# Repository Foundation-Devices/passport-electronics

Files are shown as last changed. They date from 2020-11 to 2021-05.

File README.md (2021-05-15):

# Passport Electronics

This repository contains the production circuit designs for Passport, an open source Bitcoin hardware wallet made by Foundation Devices.

main board block diagram

Above is a basic block diagram for Passport's Main Board.

## Project Structure
Passport consists of three circuit boards:
- Main Board
- Camera Board
- Battery Board

**Main Board** contains most of the components, including the processor and secure element.

**Camera Board** contains the camera and attaches to the Main Board.

**Battery Board** contains two variants – North and South – that are populated with different components. Notably, the Battery Board South contains pogo pins that provide power to the Main Board.

### Folder Organization
Each folder contains three subfolders:
- Assembly
- Fabrication
- Source Files

**Assembly** contains data for assembling components onto a bare circuit board. It includes drawings, bill of materials, and coordinates for pick-and-place and test points.

**Fabrication** contains data for the circuit board fabricator. It includes drawings, Gerber files, and coordinates for drilling and test points.

**Source Files** contains circuit board designs. It includes circuit schematics and Altium design files.

Circuit designs can only be opened with Altium. We are exploring exporting these designs in multiple file formats, including formats that can be used with open source PCB design software.

If you are interested in using KiCAD, you may try this Altium to KiCAD converter: https://github.com/thesourcerer8/altium2kicad/.

### Documenting Changes
This repository includes a CHANGES.txt file. We will document all design changes in this file. If you submit a pull request that makes changes to the circuit designs, please update CHANGES.txt with a brief description of your changes.

## Open Source Components
Passport's Main Board incorporates an open-source schematic from the [Betrusted project](https://github.com/betrusted-io/betrusted-hardware-xt). Specifically, we implemented Betrusted's [Avalance Noise Source](https://betrusted.io/avalanche-noise) design into Passport to serve as a true random number generator that does not rely on black-box silicon. Thank you to the Betrusted team for open sourcing their excellent work.

## Security Vulnerability Disclosure
Please report suspected security vulnerabilities in private to security@foundationdevices.com. Please do NOT create publicly viewable issues for suspected security vulnerabilities.

## Licensing
This project, and every file included in this repository, is licensed under CERN-OHL-S v2 – a viral, copyleft, open source license. CERN-OHL-S v2 is similar in goals to GPLv3, but is specifically designed for hardware projects.

You are welcome to use these designs for any purpose, but you must comply with the terms of the license. This includes licensing derivative work as CERN-OHL-S v2, preserving copyright notices, and more. Instructions are included in LICENSE_GUIDE.txt. Feel free to contact us with any questions about licensing.

Included in this repository in LICENSE.txt is the full text of CERN-OHL-S v2.

### License Notice
You may redistribute and modify this source and make products using it
under the terms of the CERN-OHL-S v2 (https://ohwr.org/cern_ohl_s_v2.txt).

This source is distributed WITHOUT ANY EXPRESS OR IMPLIED WARRANTY,
INCLUDING OF MERCHANTABILITY, SATISFACTORY QUALITY AND FITNESS FOR A
PARTICULAR PURPOSE. Please see the CERN-OHL-S v2 for applicable conditions.

Source location: foundationdevices.com/passport-electronics

As per CERN-OHL-S v2 section 4, should You produce hardware based on this
source, You must where practicable and applicable maintain the Source Location
visible (1) on the packaging of the hardware, (2) on the circuit board(s) via
silkscreen or copper, (3) in any documentation, and (4) on other products you
make using this source.

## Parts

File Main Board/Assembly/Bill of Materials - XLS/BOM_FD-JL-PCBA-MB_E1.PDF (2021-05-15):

Line # | Fitted | Rev | Name | Description | Designator | Quantity | Manufacturer 1 | Manufacturer Part Number 1 | Manufacturer 2 | Manufacturer Part Number 2
| Not Fitted | | 6-SNL-170(N) | Tactile Components. 6mm star dome tactile switch. | SW1, SW2, SW3, SW4, SW5, SW6, SW7, SW8, SW9, SW10, SW11, SW12, SW13, SW14, SW15, SW16, SW17, SW18 | 0
1 | Fitted | E1 | FD-JL-PCB-MB | PCB - Juliet - Main Board | PCB1 | 1
2 | Fitted | | 1-2328702-0 | 10 Position FPC Connector Contacts, Top and Bottom 0.020" (0.50mm) Surface Mount, Right Angle | J2 | 1 TE Connectivity | AMP | 1-2328702-0
4 | Fitted | | 74AUP1G09GW,125 | IC GATE AND 1CH 2-INP 5TSSOP | U1 | 1 Nexperia | | 74AUP1G09GW,125
5 | Not Fitted | | 74LVC1G04GW,125 | Inverter IC 1 Channel 5-TSSOP | U19 | 0 Nexperia | | 74LVC1G04GW,125
6 | Fitted | | 0475710001 | CONN MICRO SD CARD PUSH-PULL R/A | J1 | 1 Molex | | 0475710001
7 | Fitted | | ADP5587ACPZ-R7 | I/O Expander 18 I²C 400kHz 24-LFCSP-WQ (4x4) | U4 | 1 Analog Devices | | ADP5587ACPZ-R7
8 | Fitted | | ATECC608A-MAHCZ-T | Cryptographic Co-Processor with Secure Hardware-Based Key Storage 1-Wire Interface 8-Pin UDFN T/R | U10 | 1 Microchip | | ATECC608A-MAHCZ-T
9 | Not Fitted | | B3U-1000P | Tactile Switch SPST-NO Top Actuated Surface Mount | SW19, SW20 | 0 Omron | | B3U-1000P
10 | Fitted | | BZT585B15T-7 | Zener Diode 15V 350mW ±2% Surface Mount SOD-523 | D2, D3 | 2 Diodes | | BZT585B15T-7
11 | Fitted | | CAP CER 0.047uF 10V 10% X7R 0402 | 0.047µF ±10% 10V Ceramic Capacitor X7R 0402 (1005 Metric) | C53 | 1 Murata | | GRM155R71A473KA01D
12 | Fitted | | CAP CER 0.1uF 16V 10% X7R 0402 | 0.1µF ±10% 16V Ceramic Capacitor X7R 0402 (1005 Metric) | C1, C3, C5, C6, C7, C8, C9, C10, C11, C12, C14, C15, C18, C20, C22, C23, C25, C26, C29, C33, C34, C43, C44, C48, C52 | 25 Murata | | GCM155R71C104KA55D
12 | Not Fitted | | CAP CER 0.1uF 16V 10% X7R 0402 | 0.1µF ±10% 16V Ceramic Capacitor X7R 0402 (1005 Metric) | C2, C19 | 0 Murata | | GCM155R71C104KA55D
13 | Fitted | | CAP CER 1uF 25V 10% X5R 0402 | ±10% 25V Ceramic Capacitor X5R 0402 (1005 Metric) | C45 | 1 Samsung | | CL05A105KA5NQNC
14 | Not Fitted | | CAP CER 1.5pF 50V C0G 0402 | 1.5pF ±0.25pF 50V Ceramic Capacitor C0G, NP0 0402 (1005 Metric) | C54 | 0 Samsung | | CL05C1R5CB5NNNC
15 | Fitted | | CAP CER 4.7uF 16V 10% X5R 0603 | 4.7µF ±10% 16V Ceramic Capacitor X5R 0603 (1608 Metric) | C16, C37 | 2 TDK | | C1608X5R1C475K080AC
16 | Fitted | | CAP CER 10uF 6.3V 20% X5R 0603 | 10µF ±20% 6.3V Ceramic Capacitor X5R 0603 (1608 Metric) | C30, C31, C32, C36, C39 | 5 Samsung | | CL10A106MQ8NNNC
17 | Fitted | | CAP CER 22uF 16V 10% X5R 0805 | 22µF ±10% 16V Ceramic Capacitor X5R 0805 (2012 Metric) | C24, C27, C28 | 3 Samsung | | CL21A226KOQNNNE
18 | Fitted | | CAP CER 220pF 50V 5% C0G 0402 | 220pF ±5% 50V Ceramic Capacitor C0G, NP0 0402 (1005 Metric)C42, C47 | | 2 Samsung | | CL05C221JB5NNNC
19 | Fitted | | CAP CER 560pF 50V 10% X7R 0402 | 560pF ±10% 50V Ceramic Capacitor X7R 0402 (1005 Metric) | C21 | 1 Samsung | | CL05B561KB5NNNC
20 | Fitted | | CAP CER 1000pF 1000V 10% X7R 0805 | 1000pF ±10% 1000V (1kV) Ceramic Capacitor X7R 0805 (2012 Metric) | C17 | 1 KEMET | | C0805C102KDRACTU
21 | Fitted | | CAP CER 1500pF 50V 10% X7R 0402 | 1500pF ±10% 50V Ceramic Capacitor X7R 0402 (1005 Metric) | C41, C46, C51 | 3 Murata | | GCM155R71H152KA37D
21 | Not Fitted | | CAP CER 1500pF 50V 10% X7R 0402 | 1500pF ±10% 50V Ceramic Capacitor X7R 0402 (1005 Metric) | C38, C49 | 0 Murata | | GCM155R71H152KA37D
22 | Fitted | | CAP CER 2.2uF 6.3V 10% X5R 0402 | 2.2µF ±10% 6.3V Ceramic Capacitor X5R 0402 (1005 Metric) | C4, C13, C40, C50, C58 | 5 Samsung | | CL05A225KQ5NSNC
23 | Fitted | | CAP CER 10uF 16V 20% X5R 0603 | 10µF ±20% 16V Ceramic Capacitor X5R 0603 (1608 Metric) | C35 | 1 Murata | | GRM188R61C106MA73D
24 | Fitted | | CB2518T1R5M | 1.5µH Unshielded Wirewound Inductor 1.4A 91mOhm Max 1007 (2518 Metric) | L1 | 1 Taiyo Yuden | | CB2518T1R5M
25 | Fitted | | CB2518T4R7MRV | 4.7µH Unshielded Wirewound Inductor 820mA 130mOhm Max 1007 (2518 Metric) | L2, L3 | 2 Taiyo Yuden | | CB2518T4R7MRV
26 | Fitted | | CSTNE8M00G550000R0 | 8MHz Ceramic Resonator Built in Capacitor 33pF ±0.2% 40 Ohms -40°C ~ 85°C Surface Mount | X2 | 1 Murata | | CSTNE8M00G550000R0
27 | Fitted | | DMG2305UX-7 | P-Channel 20V 4.2A (Ta) 1.4W (Ta) Surface Mount SOT-23 | Q1 | 1 Diodes | | DMG2305UX-7
28 | Fitted | | KB DELPS2.DI-THVG-2J8L-Z555 | Blue 466nm LED Indication - Discrete 2.8V 2-SMD 0603 | LED2 | 1 Osram Opto | | KB DELPS2.DI-THVG-2J8L-Z555
29 | Fitted | | LA0151CS-TLM-E | Optical Sensor Ambient 550nm Current 4-WFBGA, CSPBGA | U5 | 1 ON | Semiconductor | LA0151CS-TLM-E
30 | Fitted | | LMV981MG/NOPB | General Purpose Amplifier 1 Circuit Rail-to-Rail SC-70-6 | U14, U16, U18 | 3 TI National | Semiconductor | LMV981MG/NOPB
31 | Fitted | | LSS-110-02-L-DV-A-K-TR | 20 Position Connector Self Mating, Non-Gendered Surface Mount Gold | P1 | 1 Samtec | | LSS-110-02-L-DV-A-K-TR
32 | Not Fitted | | LTST-C191KGKT | Green 571nm LED Indication - Discrete 2V 0603 (1608 Metric) | LED4 | 0 Vishay Lite-On | | LTST-C191KGKT
33 | Fitted | | LTST-C191KRKT | Red 631nm LED Indication - Discrete 2V 0603 (1608 Metric) | LED1 | 1 Vishay Lite-On | | LTST-C191KRKT
33 | Not Fitted | | LTST-C191KRKT | Red 631nm LED Indication - Discrete 2V 0603 (1608 Metric) | LED3 | 0 Vishay Lite-On | | LTST-C191KRKT
34 | Fitted | | MCP1501T-25E/RW | Series Voltage Reference IC 2.5V ±0.1% 8-WDFN (2x2) | U20 | 1 Microchip | | MCP1501T-25E/RW
35 | Fitted | | MCP1643-I/MC | LED Driver IC 1Output DC DC Regulator Step-Up (Boost) PWM Dimming 550mA 8-DFN (2x3) | U15 | 1 Microchip | | MCP1643-I/MC
36 | Fitted | | MLZ1608M220WT000 | 22µH Shielded Multilayer Inductor 150mA 2.4Ohm 0603 (1608 Metric) | L4 | 1 TDK | | MLZ1608M220WT000
37 | Fitted | | MMBT3906-7-F | TRANS PNP 40V 0.2A SOT23-3 | Q2 | 1 Diodes Zetex | | MMBT3906-7-F
38 | Fitted | | MX25V1635FZUI | FLASH - NOR Memory IC 16Mb (2M x 8) SPI - Quad I/O 80MHz 8-USON (2x3) | U9 | 1 Macronix | | MX25V1635FZUI
39 | Fitted | | NTK3043NT1G | N-Channel 20V 210mA (Ta) 310mW (Ta) Surface Mount SOT-723 | U8 | 1 ON | Semiconductor | NTK3043NT1G
40 | Fitted | | PUSB3AB4Z | TVS DIODE 3.3V 5V DFN2510A-10 | U6, U7 | 2 Nexperia | | PUSB3AB4Z
41 | Fitted | | RB751S40T1G | Diode Schottky 30V 30mA (DC) Surface Mount SOD-523 | D1 | 1 ON | Semiconductor | RB751S40T1G
42 | Fitted | | RES4T 0.05OHM 0.5% 1/2W 1206 | 50mOhms ±0.5% 0.5W, 1/2W Chip Resistor 1206 (3216 Metric) Current Sense | R28 | 1 Ohmite | | LVK12R050DER | Vishay Dale | WSK1206R0500FEA18
43 | Fitted | | RES 0OHM JUMPER 1/16W 0402 | 0Ohms Jumper 0.063W, 1/16W Chip Resistor 0402 (1005 Metric) | R7, R9, R54, R57 | 4 Vishay | | CRCW04020000Z0ED
43 | Not Fitted | | RES 0OHM JUMPER 1/16W 0402 | 0Ohms Jumper 0.063W, 1/16W Chip Resistor 0402 (1005 Metric) | R53, R62, R63, R67, R73 | 0 Vishay | | CRCW04020000Z0ED
44 | Fitted | | RES 1.0K 1/16W 1% 0402 | 1 kOhms ±0.5% 0.063W, 1/16W Chip Resistor 0402 (1005 Metric) Automotive AEC-Q200 Thin Film | R36, R38 | 2 Panasonic | | ERA-2AEB102X
45 | Fitted | | RES 1.0M 1/4W 5% 1206 | 1 MOhms ±5% 0.25W, 1/4W Chip Resistor 1206 (3216 Metric) Moisture Resistant Thick Film | R24 | 1 Yageo | | RC1206JR-071ML
46 | Not Fitted | | RES 1M 1/16W 1% 0402 | 1 MOhms ±1% 0.063W, 1/16W Chip Resistor 0402 (1005 Metric)R8 | | 0 Vishay | | CRCW04021M00FKED
47 | Fitted | | RES 1.8M 1/16W 1% 0402 | 1.8 MOhms ±1% 0.063W, 1/16W Chip Resistor 0402 (1005 Metric) | R35 | 1 Vishay | | CRCW04021M80FKED
48 | Fitted | | RES 4.7K 1/16W 1% 0402 | 4.7 kOhms ±1% 0.063W, 1/16W Chip Resistor 0402 (1005 Metric) Automotive AEC-Q200 Thick Film | R10, R11, R12, R13, R14, R15, R26, R59, R60 | 9 Vishay | | CRCW04024K70FKED
49 | Fitted | | RES 5.1M 1/16W 1% 0402 | 5.1 MOhms ±1% 0.1W, 1/10W Chip Resistor 0402 (1005 Metric)R43, R48 | | 2 Vishay | | CRCW04025M10FKED
50 | Fitted | | RES 6.04OHM 1/16W 1% 0402 | 6.04Ohms ±1% 0.063W, 1/16W Chip Resistor 0402 (1005 Metric) | R41 | 1 Vishay Dale | | CRCW04026R04FKED
51 | Fitted | | RES 10OHM 1/16W 1% 0402 | 10Ohms ±1% 0.063W, 1/16W Chip Resistor 0402 (1005 Metric)R5, R74 | | 2 Vishay | | CRCW040210R0FKED
52 | Fitted | | RES 10K 1/16W 1% 0402 | 10 kOhms ±1% 0.063W, 1/16W Chip Resistor 0402 (1005 Metric) | R3, R16, R17, R18, R19, R20, R21, R22, R27, R46, R51, R55, R56 | 13 Samsung | | RC1005F103CS
52 | Not Fitted | | RES 10K 1/16W 1% 0402 | 10 kOhms ±1% 0.063W, 1/16W Chip Resistor 0402 (1005 Metric) | R23 | 0 Samsung | | RC1005F103CS
55 | Fitted | | RES 21.5K 1/16W 1% 0402 | 21.5 kOhms ±1% 0.063W, 1/16W Chip Resistor 0402 (1005 Metric) | R32 | 1 Vishay | | CRCW040221K5FKED
56 | Fitted | | RES 22K 1/16W 1% 0402 | 22 kOhms ±1% 0.063W, 1/16W Chip Resistor 0402 (1005 Metric) | R6, R25, R33, R52 | 4 Vishay | | CRCW040222K0FKED
58 | Fitted | | RES 47.5K 1/16W 1% 0402 | 47.5 kOhms ±1% 0.063W, 1/16W Chip Resistor 0402 (1005 Metric) | R34 | 1 Vishay | | CRCW040247K5FKED
59 | Fitted | | RES 100K 1/16W 0.5% 0402 | 100 kOhms ±0.5% 0.063W, 1/16W Chip Resistor 0402 (1005 Metric) | R39 | 1 Vishay Dale | | CRCW0402100KDHEDP
60 | Fitted | | RES 100K 1/16W 1% 0402 | 100 kOhms ±1% 0.063W, 1/16W Chip Resistor 0402 (1005 Metric) Automotive AEC-Q200 Thick Film | R1, R2, R4, R30, R40, R42, R47 | 7 Vishay | | CRCW0402100KFKED
60 | Not Fitted | | RES 100K 1/16W 1% 0402 | 100 kOhms ±1% 0.063W, 1/16W Chip Resistor 0402 (1005 Metric) Automotive AEC-Q200 Thick Film | R58, R68 | 0 Vishay | | CRCW0402100KFKED
61 | Fitted | | RES 200K 1/16W 1% 0402 | 200 kOhms ±1% 0.063W, 1/16W Chip Resistor 0402 (1005 Metric) Moisture Resistant Thick Film | R29, R31, R37 | 3 Vishay Dale | | CRCW0402200KFKTD
62 | Fitted | | RES 220K 1/16W 1% 0402 | 220 kOhms ±1% 0.063W, 1/16W Chip Resistor 0402 (1005 Metric) | R45, R50, R61 | 3 Vishay | | CRCW0402220KFKED
63 | Not Fitted | | RES 330OHM 1/16W 1% 0402 | 330Ohms ±1% 0.063W, 1/16W Chip Resistor 0402 (1005 Metric) Moisture Resistant Thick Film | R65, R66 | 0 Vishay | | CRCW0402330RFKED
64 | Fitted | | RES 470K 1/16W 1% 0402 | 470 kOhms ±1% 0.063W, 1/16W Chip Resistor 0402 (1005 Metric) | R44, R49 | 2 Vishay | | CRCW0402470KFKED
65 | Fitted | | SFV4R-2STE1HLF | 4 Position FFC, FPC Connector Contacts, Top 0.020" (0.50mm) Surface Mount, Right Angle | J3 | 1 Amphenol ICC / | FCI | SFV4R-2STE1HLF
66 | Fitted | | STM32H753VIT6 | ARM® Cortex®-M7 STM32H7 Microcontroller IC 32-Bit 480MHz 2MB (2M x 8) FLASH 100-LQFP (14x14) | U2 | 1 STMicroelectronic | s | STM32H753VIT6
67 | Not Fitted | | TPS3840DL27DBVR | Supervisor 2.7V Open Drain 1 Channel SOT-23-5 | U3 | 0 Texas Instruments TPS3840DL27DBVR
68 | Fitted | | TPS61158DRVR | LED Driver IC 1Output DC DC Regulator Step-Up (Boost) PWM Dimming 30mA 6-WSON (2x2) | U17 | 1 Texas Instruments TPS61158DRVR
69 | Fitted | | TPS61220DCKR | Boost Switching Regulator IC Positive Adjustable 1.8V 1 Output 200mA (Switch) 6-TSSOP, SC-88, SOT-363 | U13 | 1 Texas Instruments TPS61220DCKR
70 | Fitted | | TPS63030DSKR | Buck-Boost Switching Regulator IC Positive Adjustable 1.2V 1 Output 900mA (Switch) 10-WFDFN Exposed Pad | U11 | 1 Texas Instruments TPS63030DSKR
71 | Fitted | | TPS79928YZUR | Linear Voltage Regulator IC 1Output 200mA 5-DSBGA (1x1.37) | U21 | 1 Texas Instruments TPS79928YZUR
72 | Fitted | | XC6192AA05ER-G | Power Switch/Driver 1:1 P-Channel 400mA USP-8B06 | U12 | 1 Torex | | XC6192AA05ER-G

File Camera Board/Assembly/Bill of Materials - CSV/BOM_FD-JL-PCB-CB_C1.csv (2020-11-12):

Line # | Fitted | Rev | Name | Description | Designator | Quantity | Manufacturer 1 | Manufacturer Part Number 1
1 | Fitted |  | CAP CER 4.7uF 16V 10% X5R 0603 | 4.7µF ±10% 16V Ceramic Capacitor X5R 0603 (1608 Metric) | C1, C2, C5, C6 | 4 | TDK | C1608X5R1C475K080AC
2 | Fitted |  | CAP CER 0.1uF 16V 10% X7R 0402 | 0.1µF ±10% 16V Ceramic Capacitor X7R 0402 (1005 Metric) | C3, C4, C7, C8, C9 | 5 | Murata | GCM155R71C104KA55D
3 | Fitted |  | BLM18PG221SH1D | FERRITE BEAD 220 OHM 0603 1LN | L1, L2 | 2 | Murata | BLM18PG221SH1D
4 | Fitted |  | LSS-110-02-L-DV-A-K | 20 Position Connector Self Mating, Non-Gendered Surface Mount Gold | P1 | 1 | Samtec | LSS-110-02-L-DV-A-K
5 | Fitted | C1 | FD-JL-PCB-CB | PCB - Juliet - Camera Board | PCB1 | 1
6 | Fitted |  | RES 4.7K 1/16W 1% 0402 | 4.7 kOhms ±1% 0.063W, 1/16W Chip Resistor 0402 (1005 Metric) Automotive AEC-Q200 Thick Film | R1, R2 | 2 | Vishay | CRCW04024K70FKED
7 | Not Fitted |  | RES 0 OHM JUMPER 1/16W 0402 | 0 Ohms Jumper 0.063W, 1/16W Chip Resistor 0402 (1005 Metric) | R4 | 0 | Vishay | CRCW04020000Z0ED
7 | Fitted |  | RES 0 OHM JUMPER 1/16W 0402 | 0 Ohms Jumper 0.063W, 1/16W Chip Resistor 0402 (1005 Metric) | R5 | 1 | Vishay | CRCW04020000Z0ED
8 | Fitted |  | OVM7690-RYAA | SENSOR CAMERA CMOS 20CAMERACUBE | U1 | 1 | OmniVision Technologies | OVM7690-R20A
9 | Fitted |  | DSC6001HE2A-024.0000 | XO (Standard) CMOS Oscillator 1.8V ~ 3.3V Enable/Disable 4-SMD, No Lead | X1 | 1 | Microchip | DSC6001HE2A-024.0000

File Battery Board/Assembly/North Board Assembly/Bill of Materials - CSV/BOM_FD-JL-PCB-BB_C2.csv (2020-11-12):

Line # | Fitted | Rev | Name | Description | Quantity | Designator | Manufacturer 1 | Manufacturer Part Number 1
1 | Fitted | C2 | FD-JL-PCB-BB | PCB - Juliet - Battery Board | 1 | PCB1
2 | Fitted |  | SMTSO-080-4ET | Surface Mount Nut | 1 | N1 | PennEngineering | SMTSO-080-4ET
3 | Fitted |  | RES 0 OHM JUMPER 1/8W 0805 | 0 Ohms Jumper 0.125W, 1/8W Chip Resistor 0805 (2012 Metric) | 1 | R1 | Vishay | CRCW08050000Z0EA
4 | Fitted |  | 0393-0-00-15-00-00-09-0* | Pin Receptacle Connector 0.065" ~ 0.082" (1.65mm ~ 2.08mm) No Tail Solder | 1 | P2 | Mill-Max | 0393-0-00-15-00-00-09-0*
5 | Fitted |  | 0871-0-57-20-82-14-11-0 | Contact Spring Surface Mount | 1 | P3 | Mill-Max | 0871-0-57-20-82-14-110
6 | Not Fitted |  | 829-22-002-20-002101 | 2 Position Spring Piston Connector Through Hole, Right Angle | 0 | P1 | Mill-Max | 829-22-002-20-002101

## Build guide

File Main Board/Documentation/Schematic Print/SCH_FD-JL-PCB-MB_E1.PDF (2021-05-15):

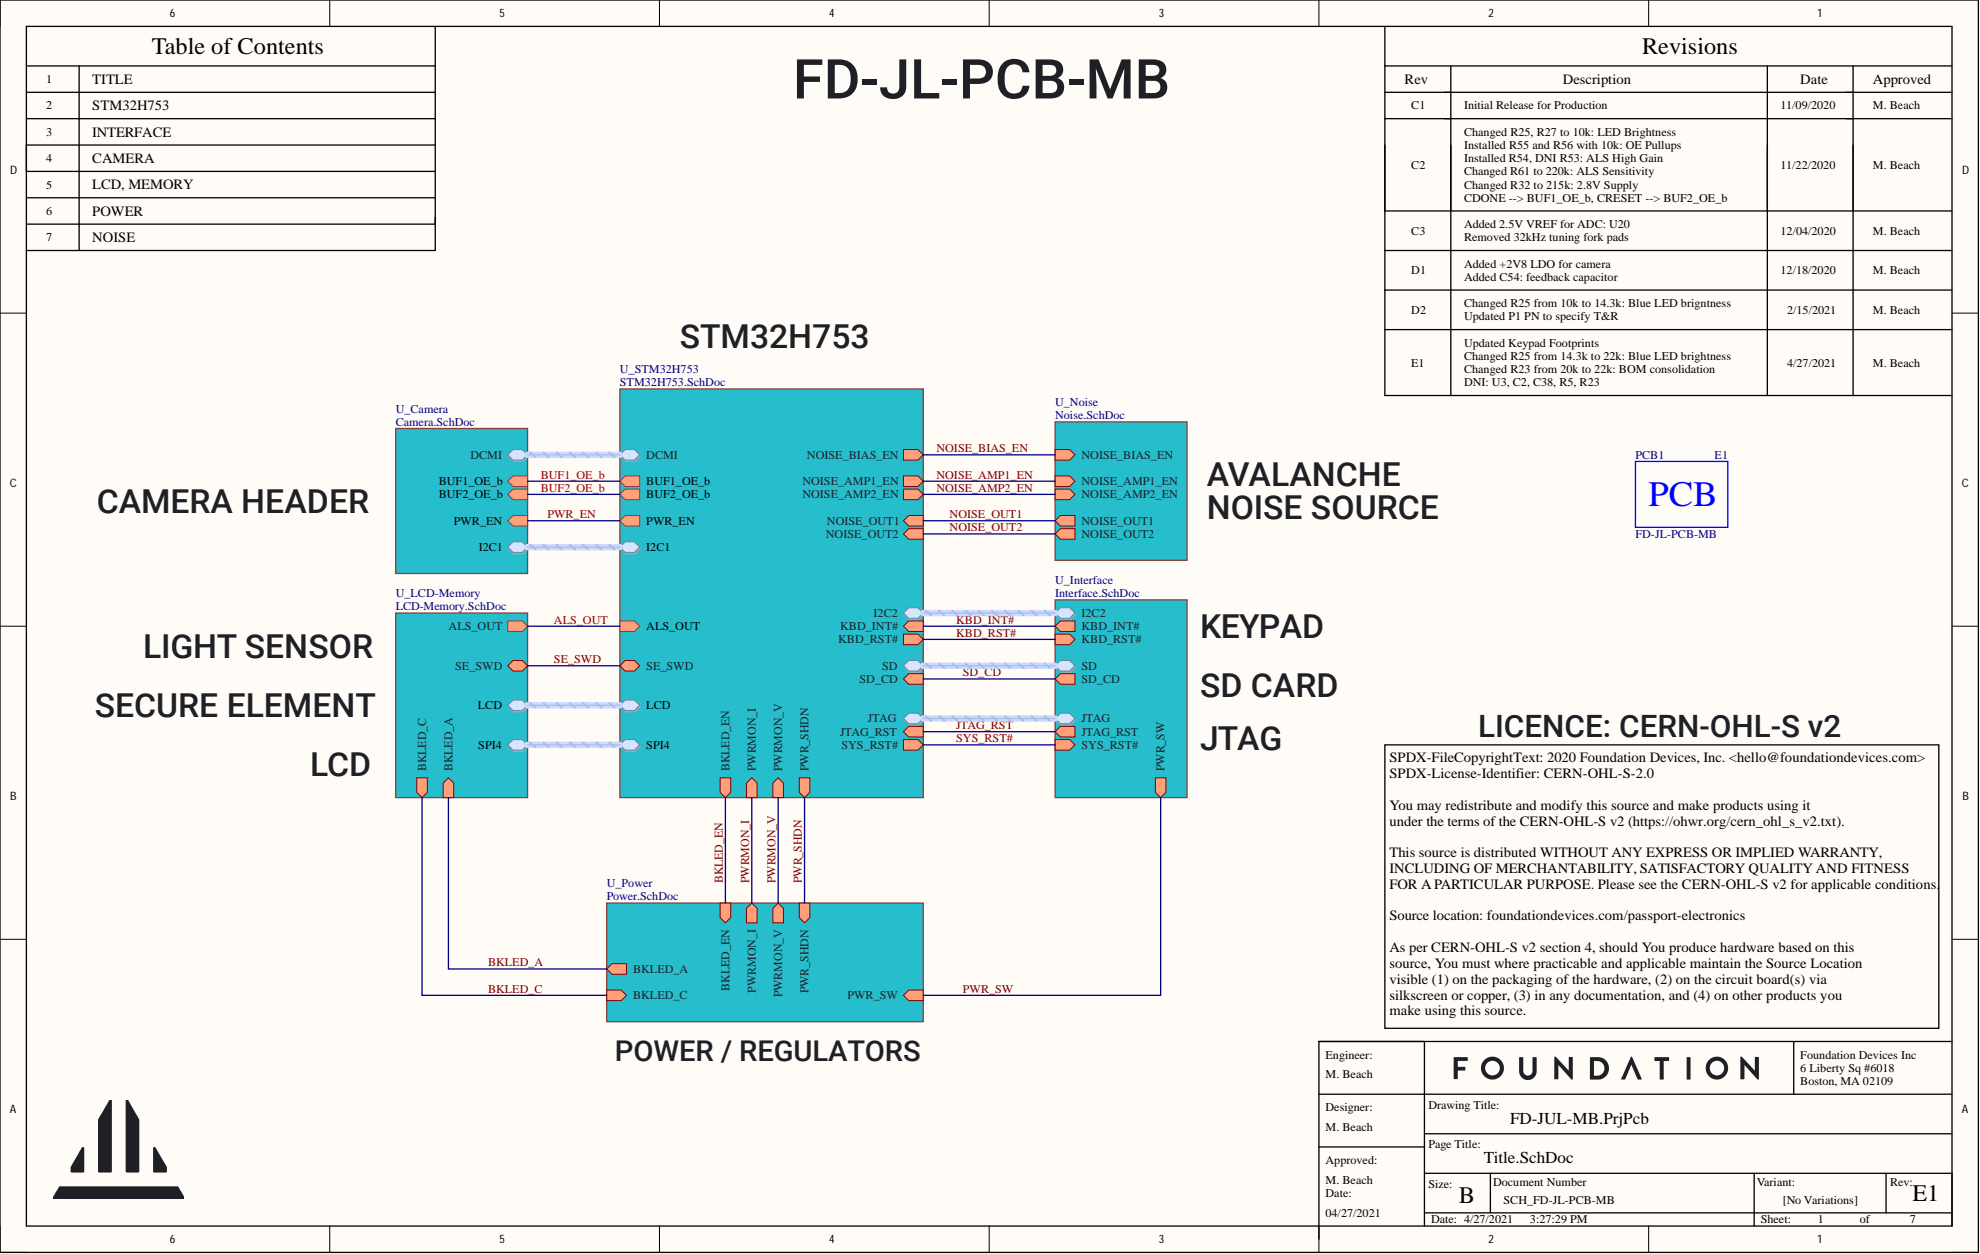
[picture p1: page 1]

FD-JL-PCB-MB

Table of Contents | STM32H753 U_STM32H753 STM32H753.SchDoc | Revisions

TITL E | | Rev | Description | Date | Approve d

234567 | CAMERA

STM32H753 | | C1 | Initial Release for Production | 11/09/2020 | M. Beach

INTERFACE | | C2 | Changed R25, R27 to 10k: LED Brightness Installed R55 and R56 with 10k: OE Pullups Installed R54, DNI R53: ALS High Gain Changed R61 to 220k: ALS Sensitivity Changed R32 to 215k: 2.8V Supply CDONE --> BUF1_OE_b, CRESET --> BUF2_OE_b | 11/22/2020 | M. Beach

LCD, MEMOR Y

POWER

C3 | Added 2.5V VREF for ADC: U20 Removed 32kHz tuning fork pads | 12/04/2020 | M. Beach

NOISE

D1 | Added +2V8 LDO for camera Added C54: feedback capacitor | 12/18/2020 | M. Beach

D2 | Updated P1 PN to specify T&R | 2/15/2021 | M. Beach Changed R25 from 10k to 14.3k: Blue LED brigntness

E1 | Updated Keypad Footprints Changed R25 from 14.3k to 22k: Blue LED brightness Changed R23 from 20k to 22k: BOM consolidation DNI: U3, C2, C38, R5, R23 | 4/27/2021 | M. Beach

BUF1_OE_b | NOISE_AMP1_EN
BUF2_OE_b | NOISE_AMP2_EN

PWR_EN | NOISE_OUT1

SPDX-FileCopyrightText: 2020 Foundation Devices, Inc. <hello@foundationdevices.com>
SPDX-License-Identifier: CERN-OHL-S-2.0 You may redistribute and modify this source and make products using it

under the terms of the CERN-OHL-S v2 (https://ohwr.org/cern_ohl_s_v2.txt).

This source is distributed WITHOUT ANY EXPRESS OR IMPLIED
INCLUDING OF MERCHANTABILITY, SATISFACTORY QUALITY AND FITNESS
FOR

PARTICULAR PURPOSE. Please see the CERN-OHL-S v2 for applicable conditions.

Source location: foundationdevices.com/passport-electronic

As per CERN-OHL-S v2 section 4, should
source,
visible (1) on the packaging of the hardware, (2) on the circuit board(s) via
silkscreen or copper, (3) in any documentation, and (4) on other products you
make using this source.

You produce hardware based on this

You must where practicable and applicable maintain the Source Location

Engineer: | | Foundation Devices Inc 6 Liberty Sq #6018 Boston, MA 02109 M. Beach

Designer: M. Beach | Drawing Title: FD-JUL-MB.PrjPcb

Size: B | Document Number SCH_FD-JL-PCB-MB | Variant: [No Variations] | Rev: E1

Date: 4/27/2021 3:27:29 PM | | Sheet: 1 of

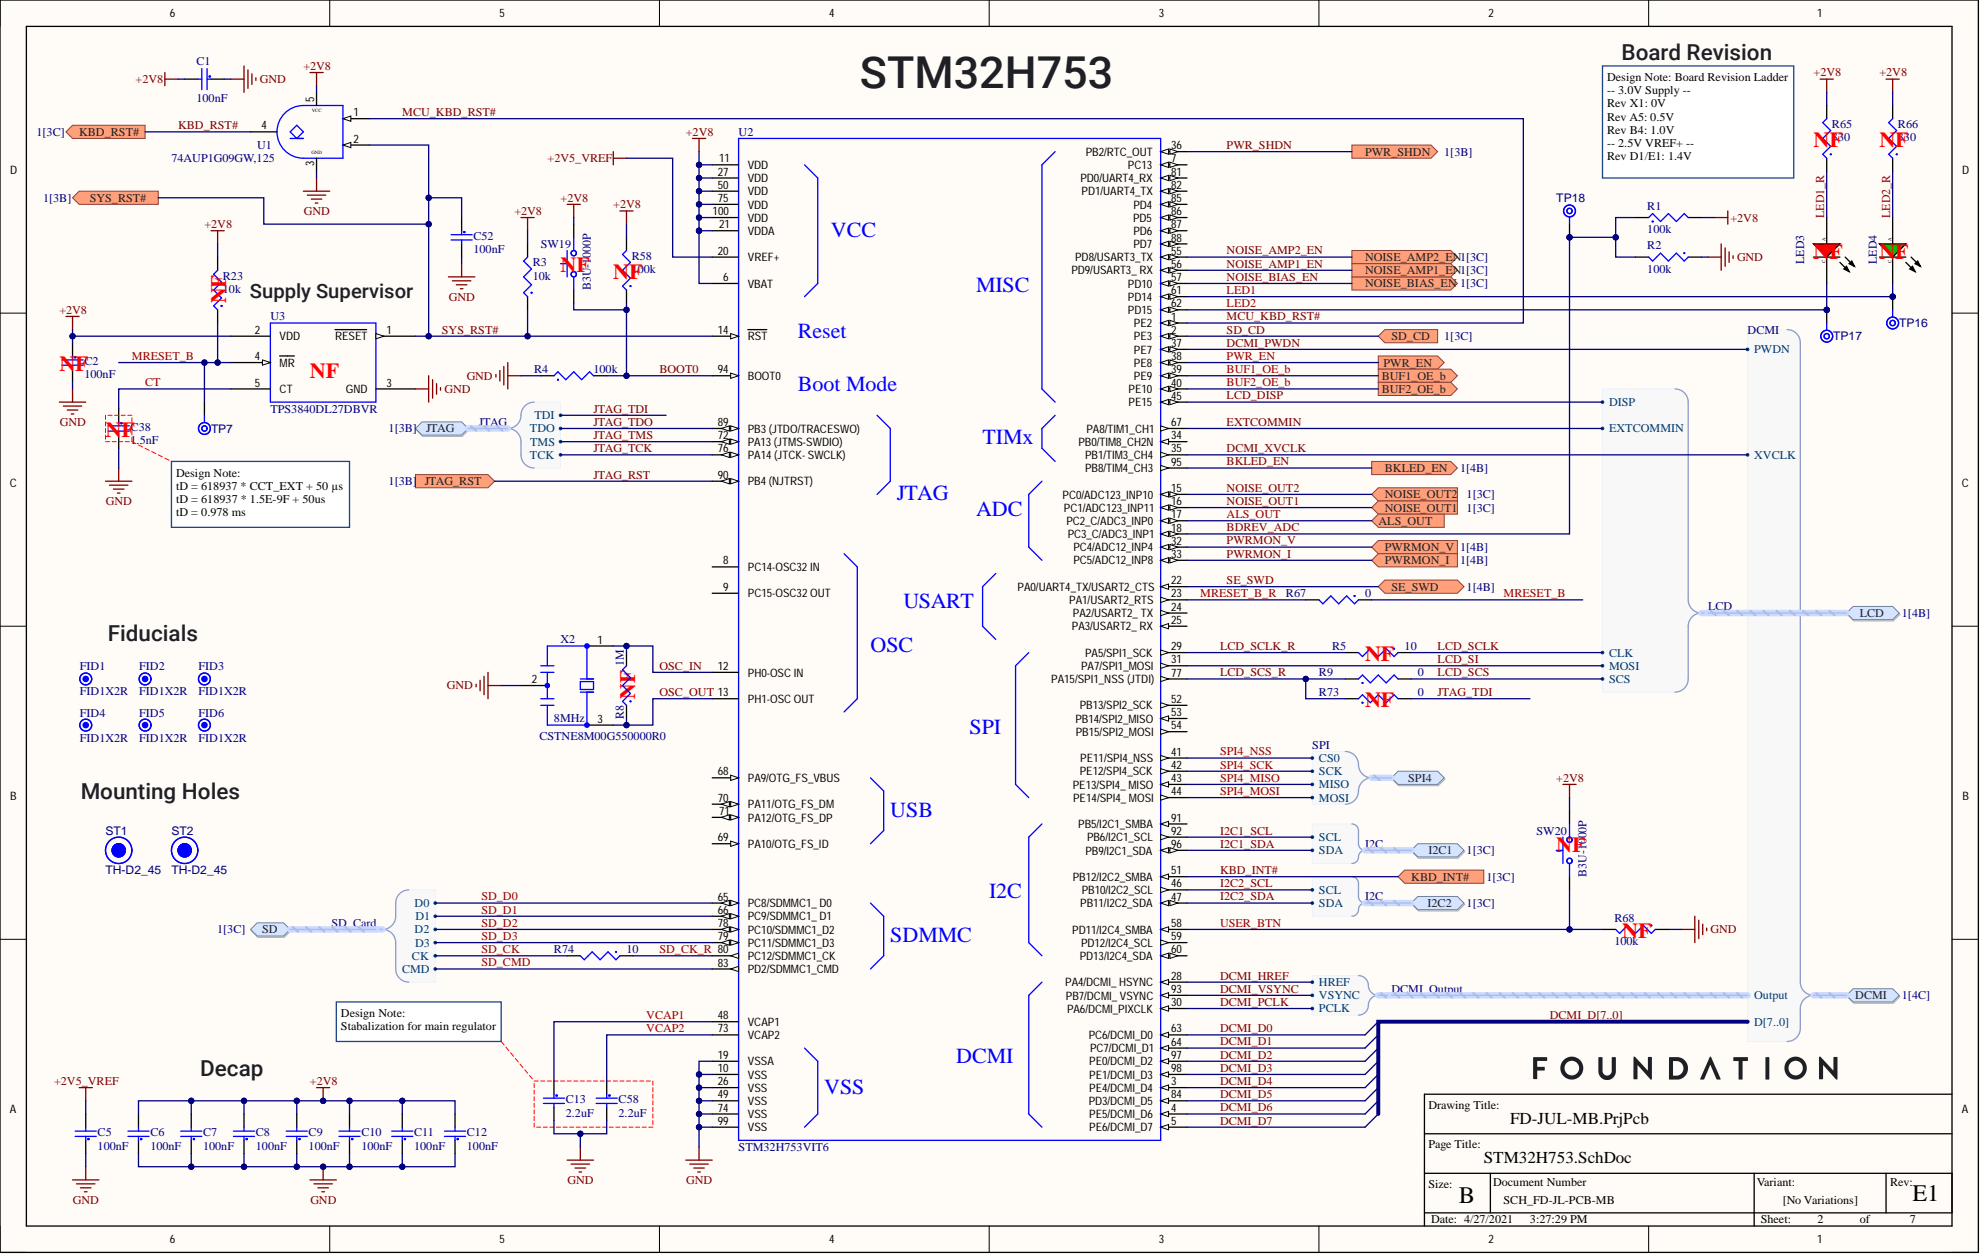
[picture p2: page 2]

VDD 27
VDD 50
VDD 75
VDD 100
VDDA 21

GND

VREF+ 20

NOISE_AMP2_EN NOISE_AMP2_EN1[3C] NOISE_AMP1_EN NOISE_AMP1_EN1[3C] NOISE_BIAS_EN 1[3C] NOISE_BIAS_EN

LED1
LED2

PH1-OSC OUT 13

SPI4_NSS SPI4_SCK SPI4_MISO | R73

Design Note:
Stabalization for main regulator

VCAP2 | VCAP2 73

VSSA 19

FD-JUL-MB.PrjPcb

B | Variant: | Rev:

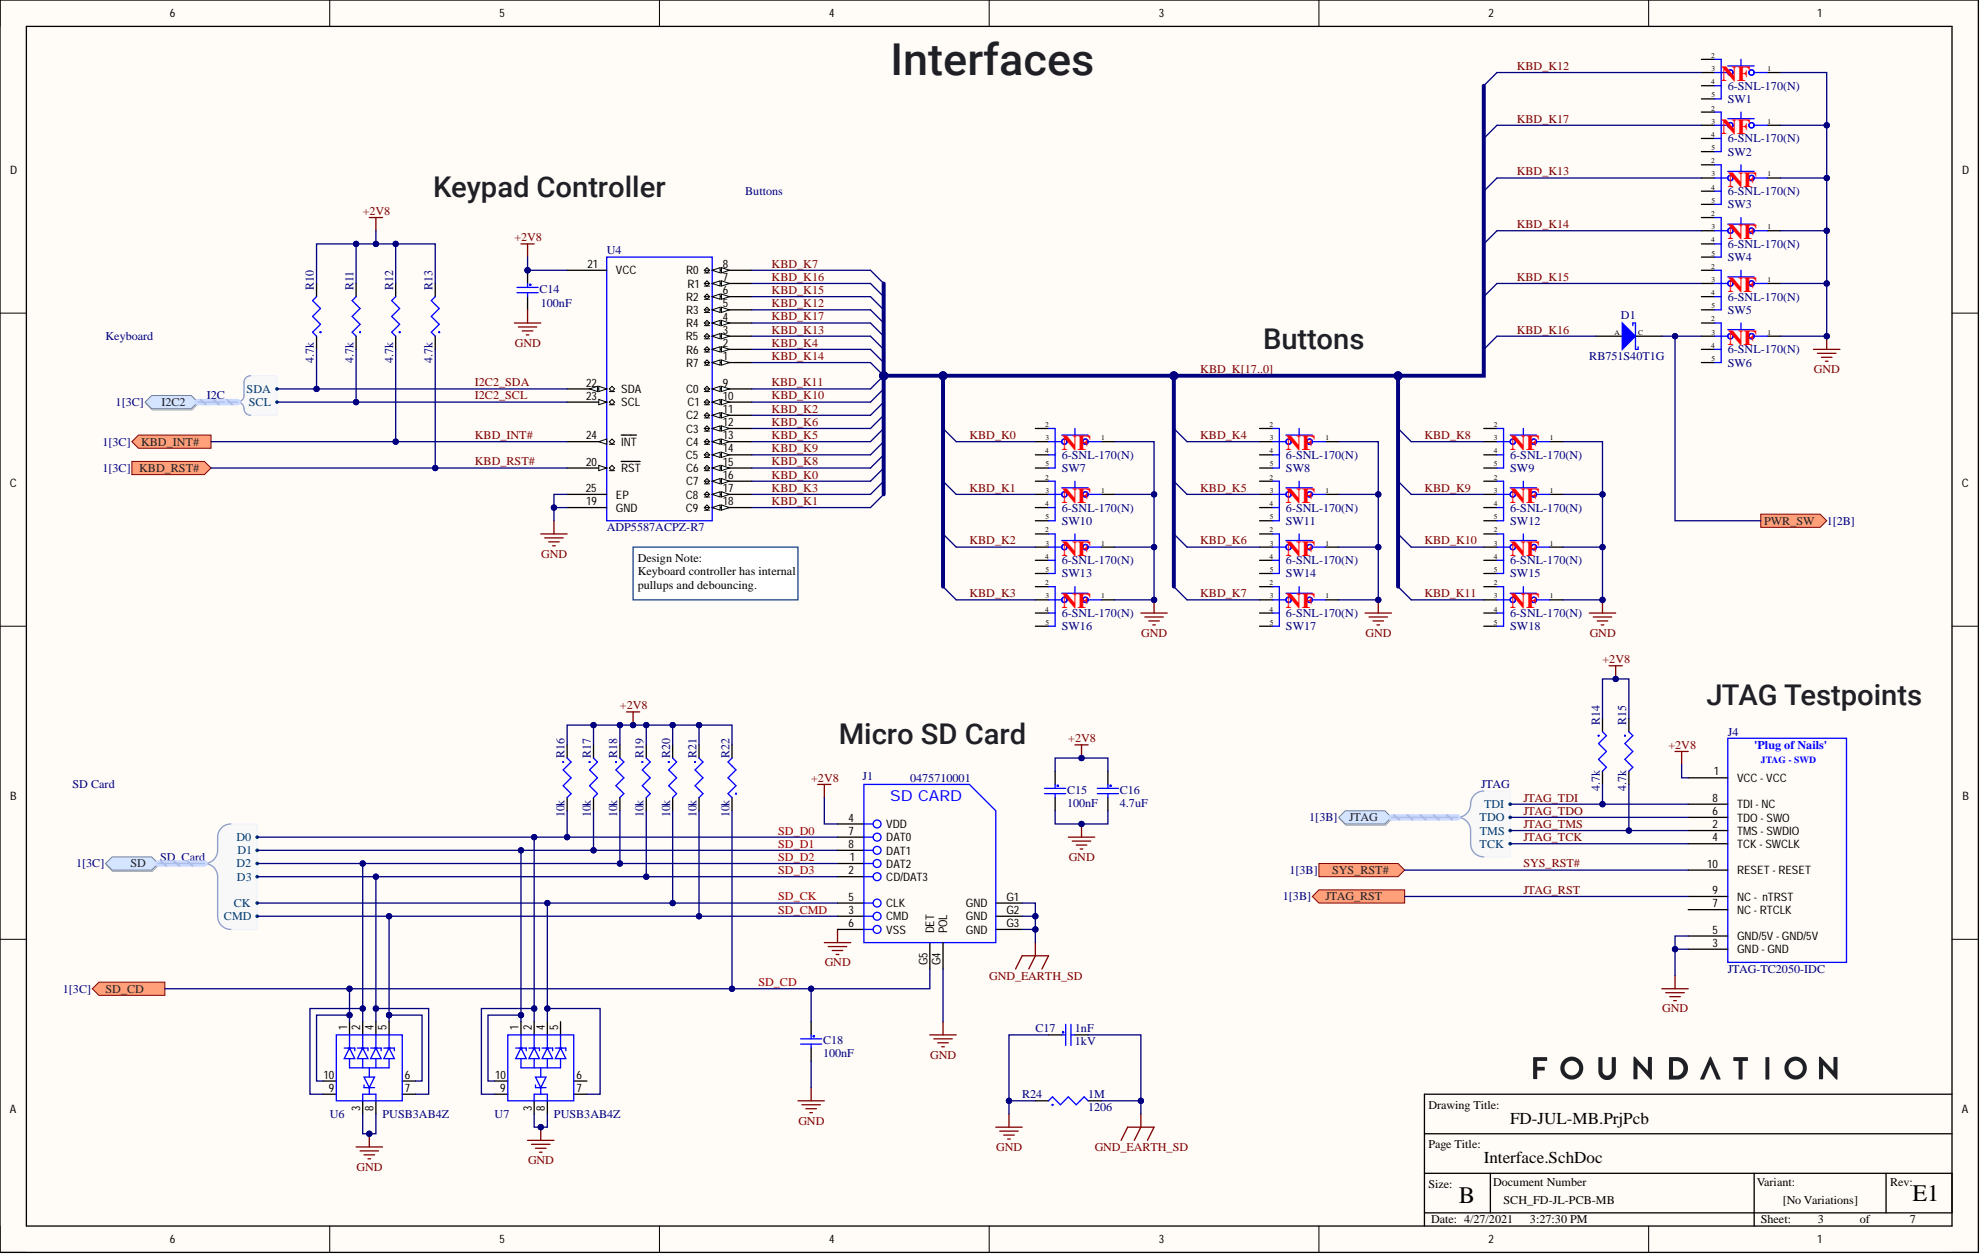
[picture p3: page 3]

Design Note:
Keyboard controller has internal
pullups and debouncing.

FD-JUL-MB.PrjPcb

Size: B | | Rev: E1 Variant:

Date: 4/27/2021 3:27:30 PM | Sheet: 3 of 7

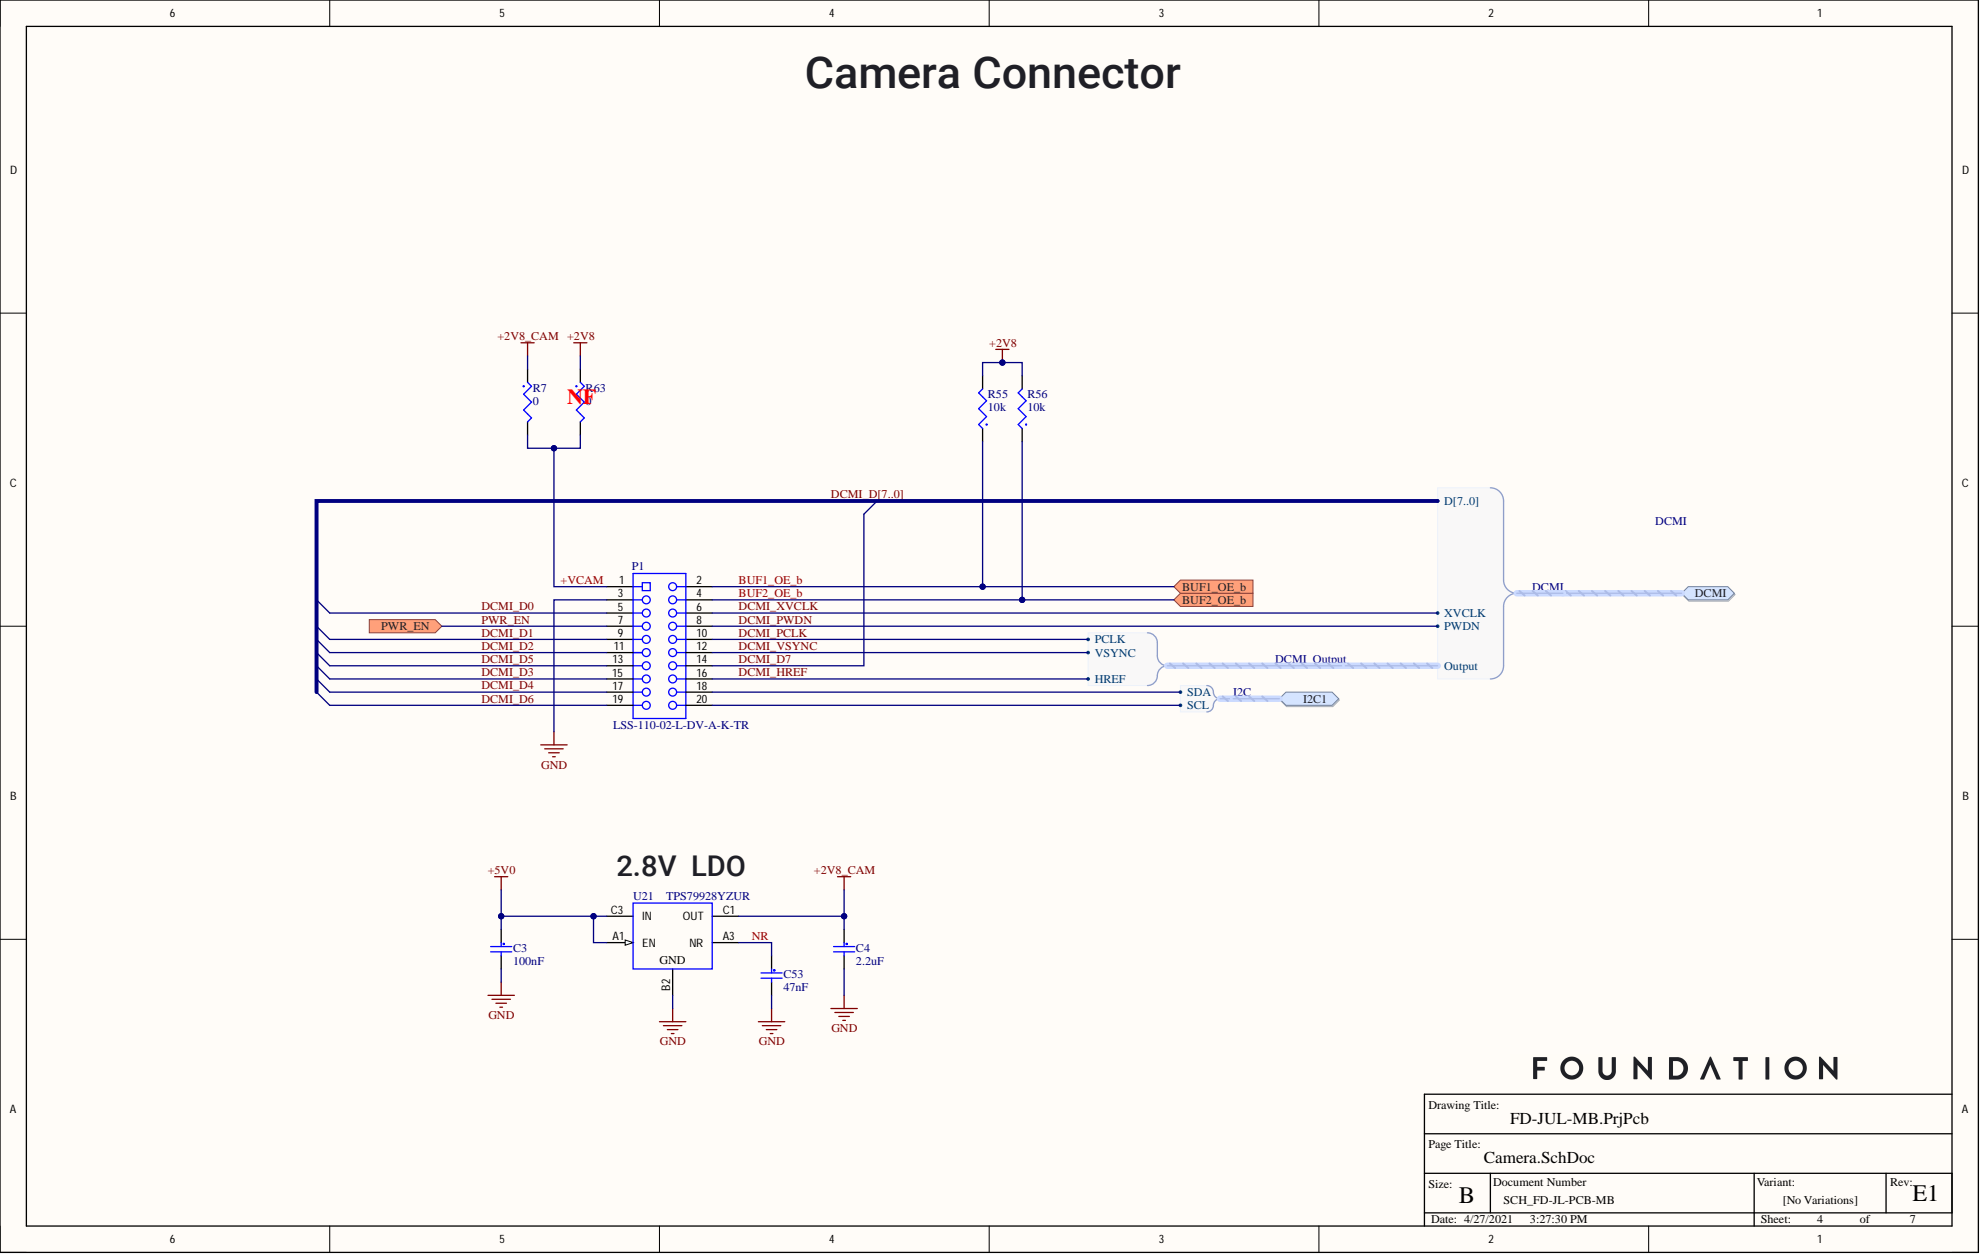
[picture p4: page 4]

FD-JUL-MB.PrjPcb

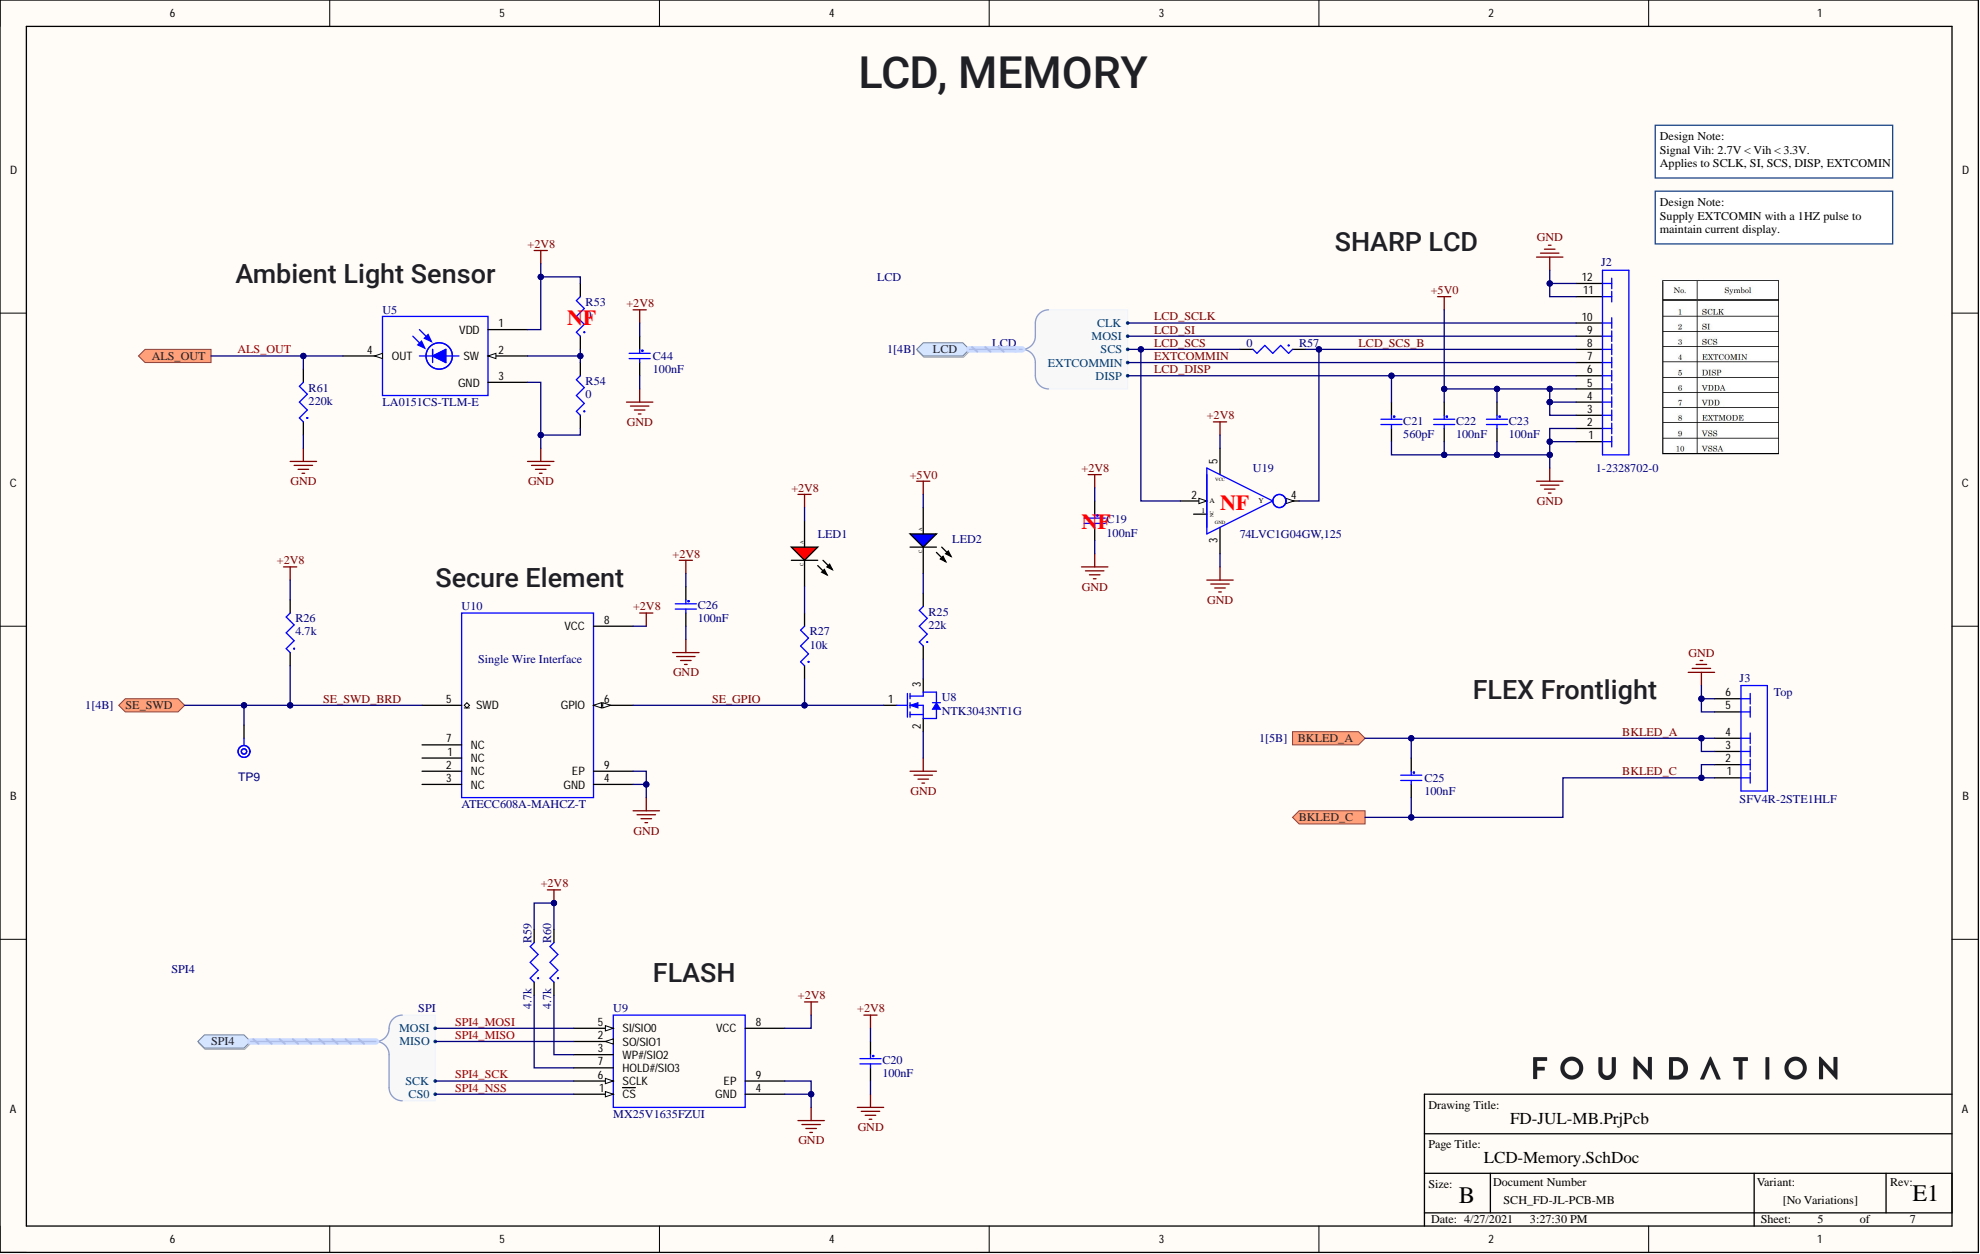
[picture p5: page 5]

Design Note:
Signal Vih: 2.7V < Vih < 3.3V.
Applies to SCLK, SI, SCS, DISP, EXTCOMIN

Supply EXTCOMIN with a 1HZ pulse to
maintain current display.

LCD_DISP | | | 6

FD-JUL-MB.PrjPcb

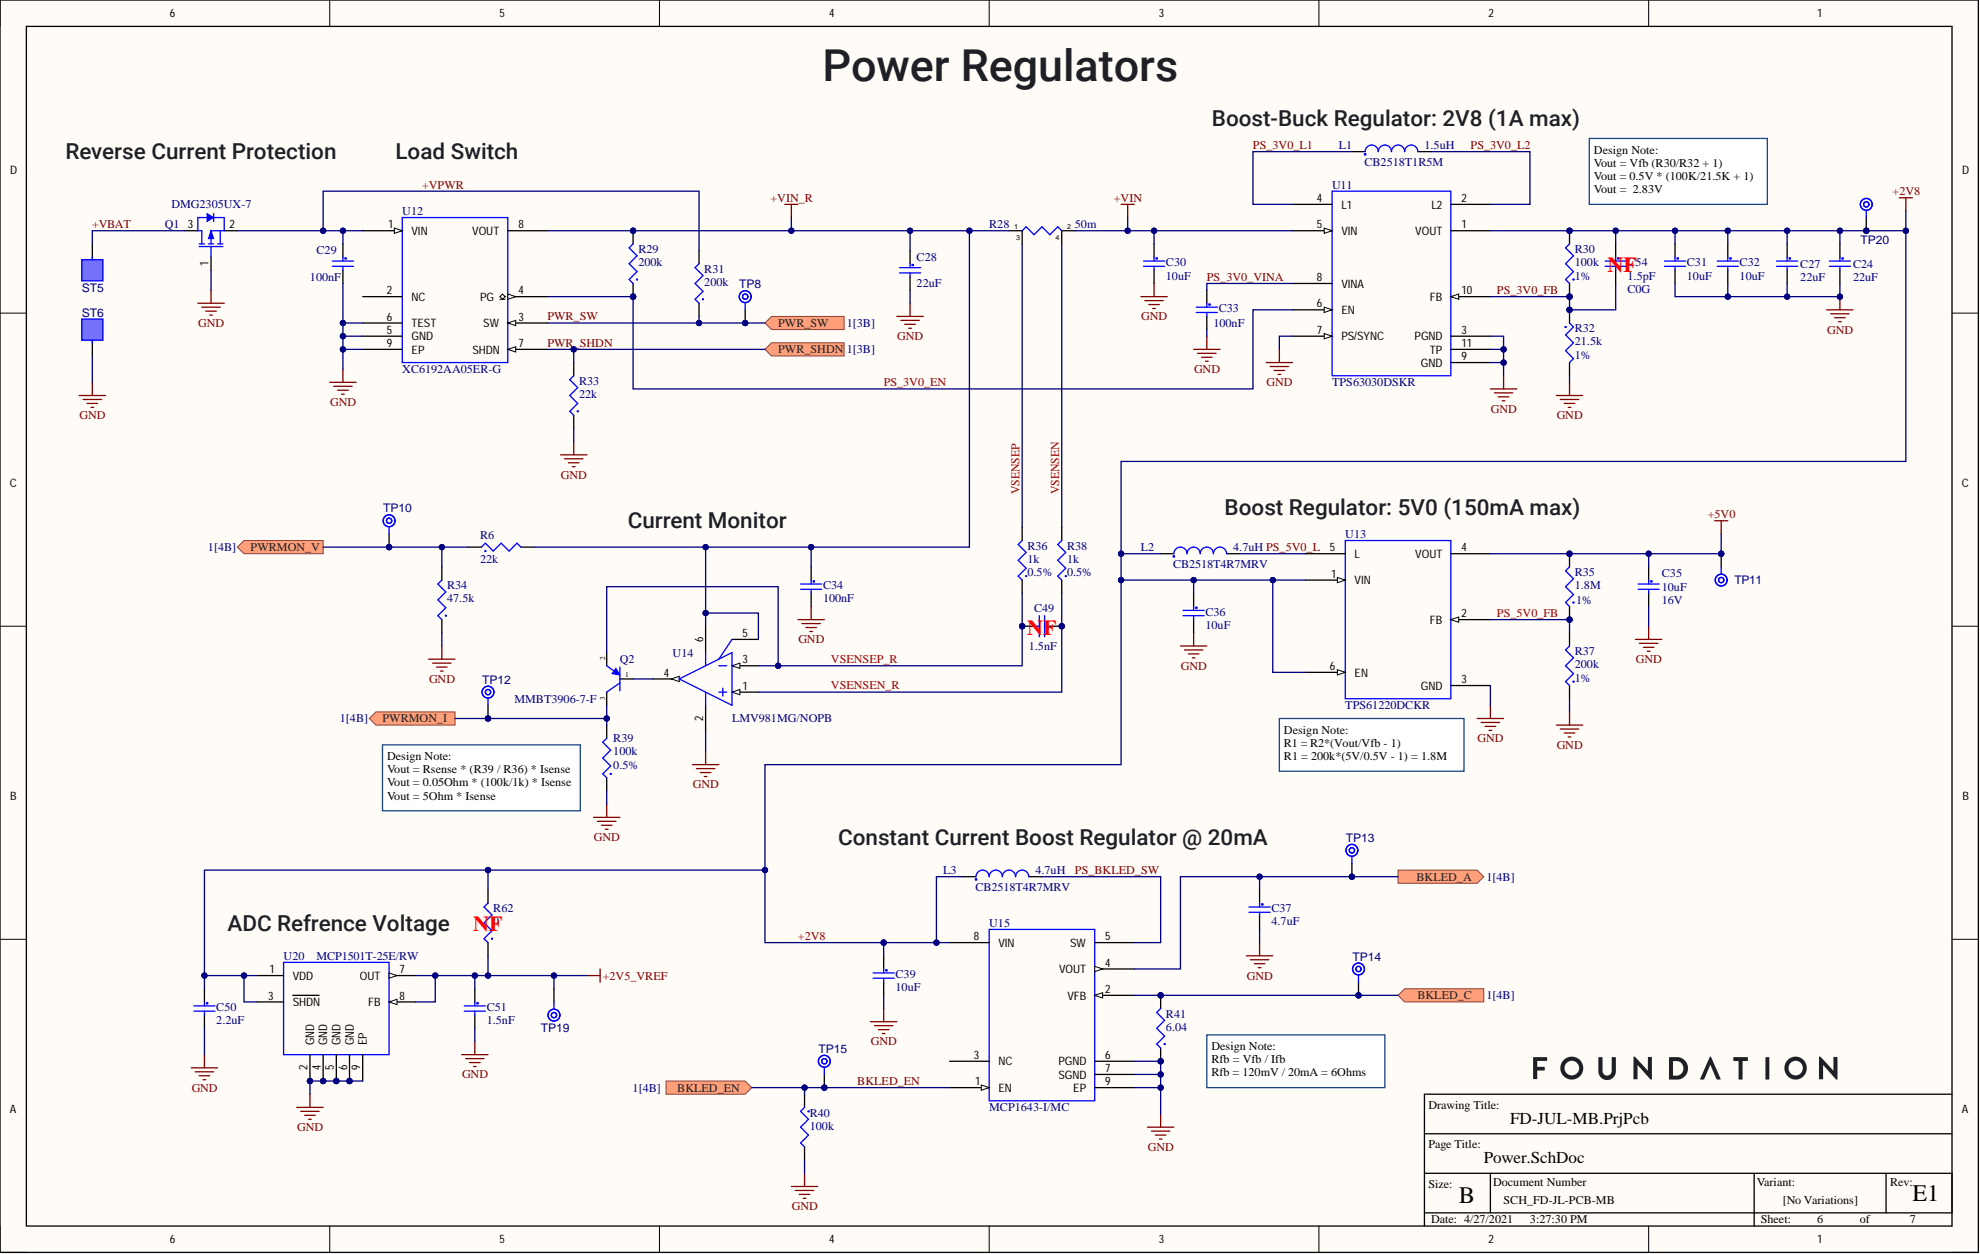
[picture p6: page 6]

Boost-Buck Regulator: 2V8 (1A max)

VSENSEP_R

1 | VSENSEN_R

Constant Current Boost Regulator @ 20mA

ADC Refrence Voltage NF

FD-JUL-MB.PrjPcb

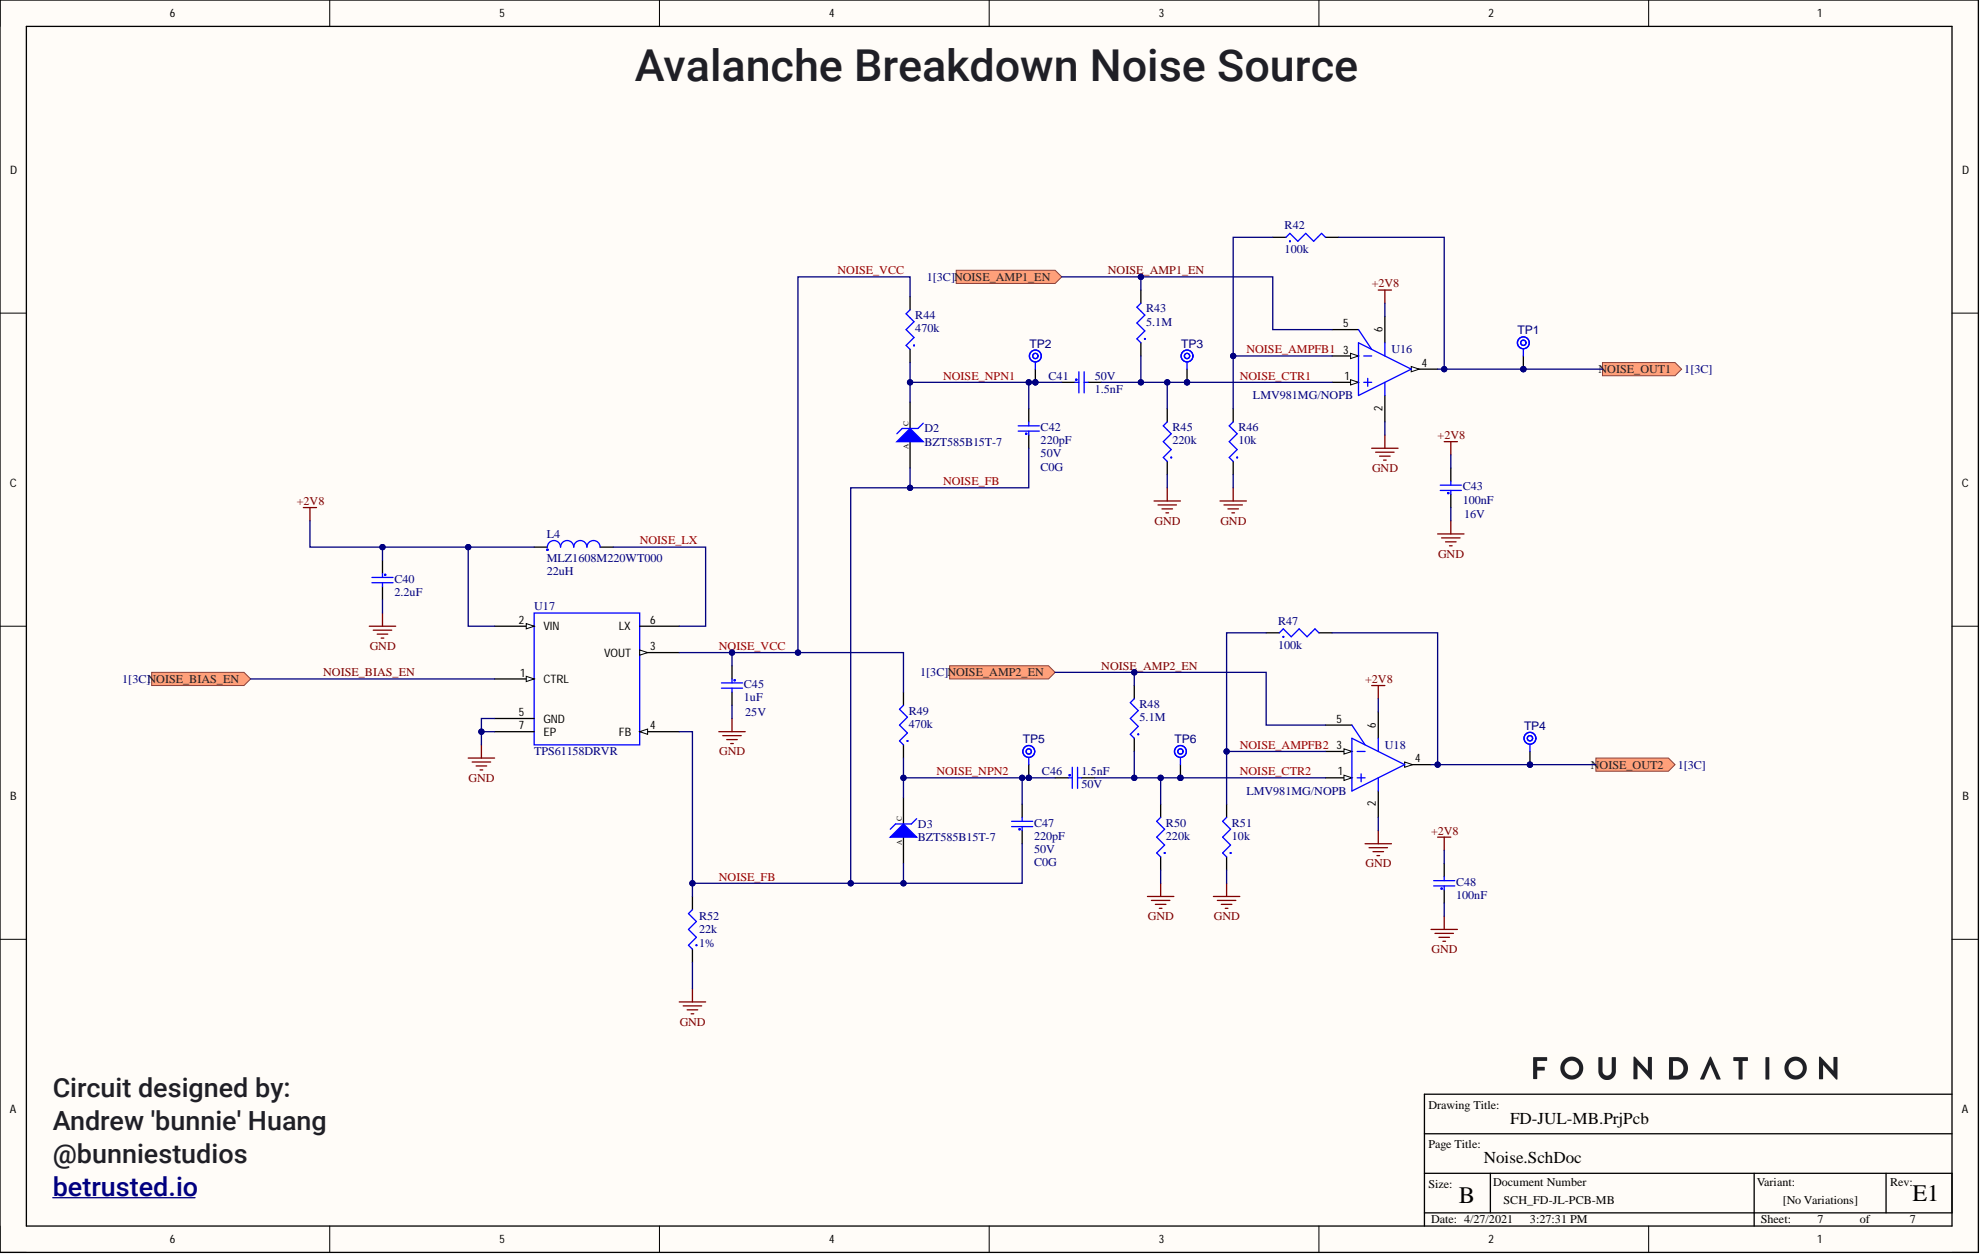
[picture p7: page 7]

Avalanche Breakdown Noise Source

NOISE_AMPFB1

NOISE_CTR1

NOISE_AMPFB2

NOISE_CTR2

FD-JUL-MB.PrjPcb

B | Variant: | Rev:

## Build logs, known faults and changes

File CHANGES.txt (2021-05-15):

Use this file to document changes made to the designs. 

As per section 3.3.b of LICENSE.txt, information should be added but NEVER REMOVED from this file. 

When adding information, please provide a brief entry with a date and the nature of the modification for each design change.

CHANGES:

REV C1: 11/09/2020
 - Initial Release

REV C2: 11/22/2020
 - Changed R25, R27, to 10kOhms: LED Brightness
 - Installed R55 and R56 with 10kOhms
 - Changed R61 to 220k: ALS Sensitivity
 - Changed R32 to 215k: 2.8V Supply
 - Net name change: CDONE --> BUF1_OE_b, CRESET --> BUF2_OE_b

REV C3: 12/04/2020
 - Added 2.5V VREF for ADC: U20
 - Removed 32kHz tuning fork

REV D1: 12/18/2020
 - Added +2V8 LDO for camera
 - Added C54: feedback capacitor

REV D2: 2/15/2021
 - Changed R25 from 10k to 14.3k: Blue LED brigntness
 - Updated P1 PN to specify T&R

REV E1: 4/27/2021
 - Updated Keypad Footprints
 - Changed R25 from 14.3k to 22k: Blue LED brightness
 - Changed R33 from 20k to 22k: BOM consolidation
 - DNI: U3, C2, C38, R5, R23

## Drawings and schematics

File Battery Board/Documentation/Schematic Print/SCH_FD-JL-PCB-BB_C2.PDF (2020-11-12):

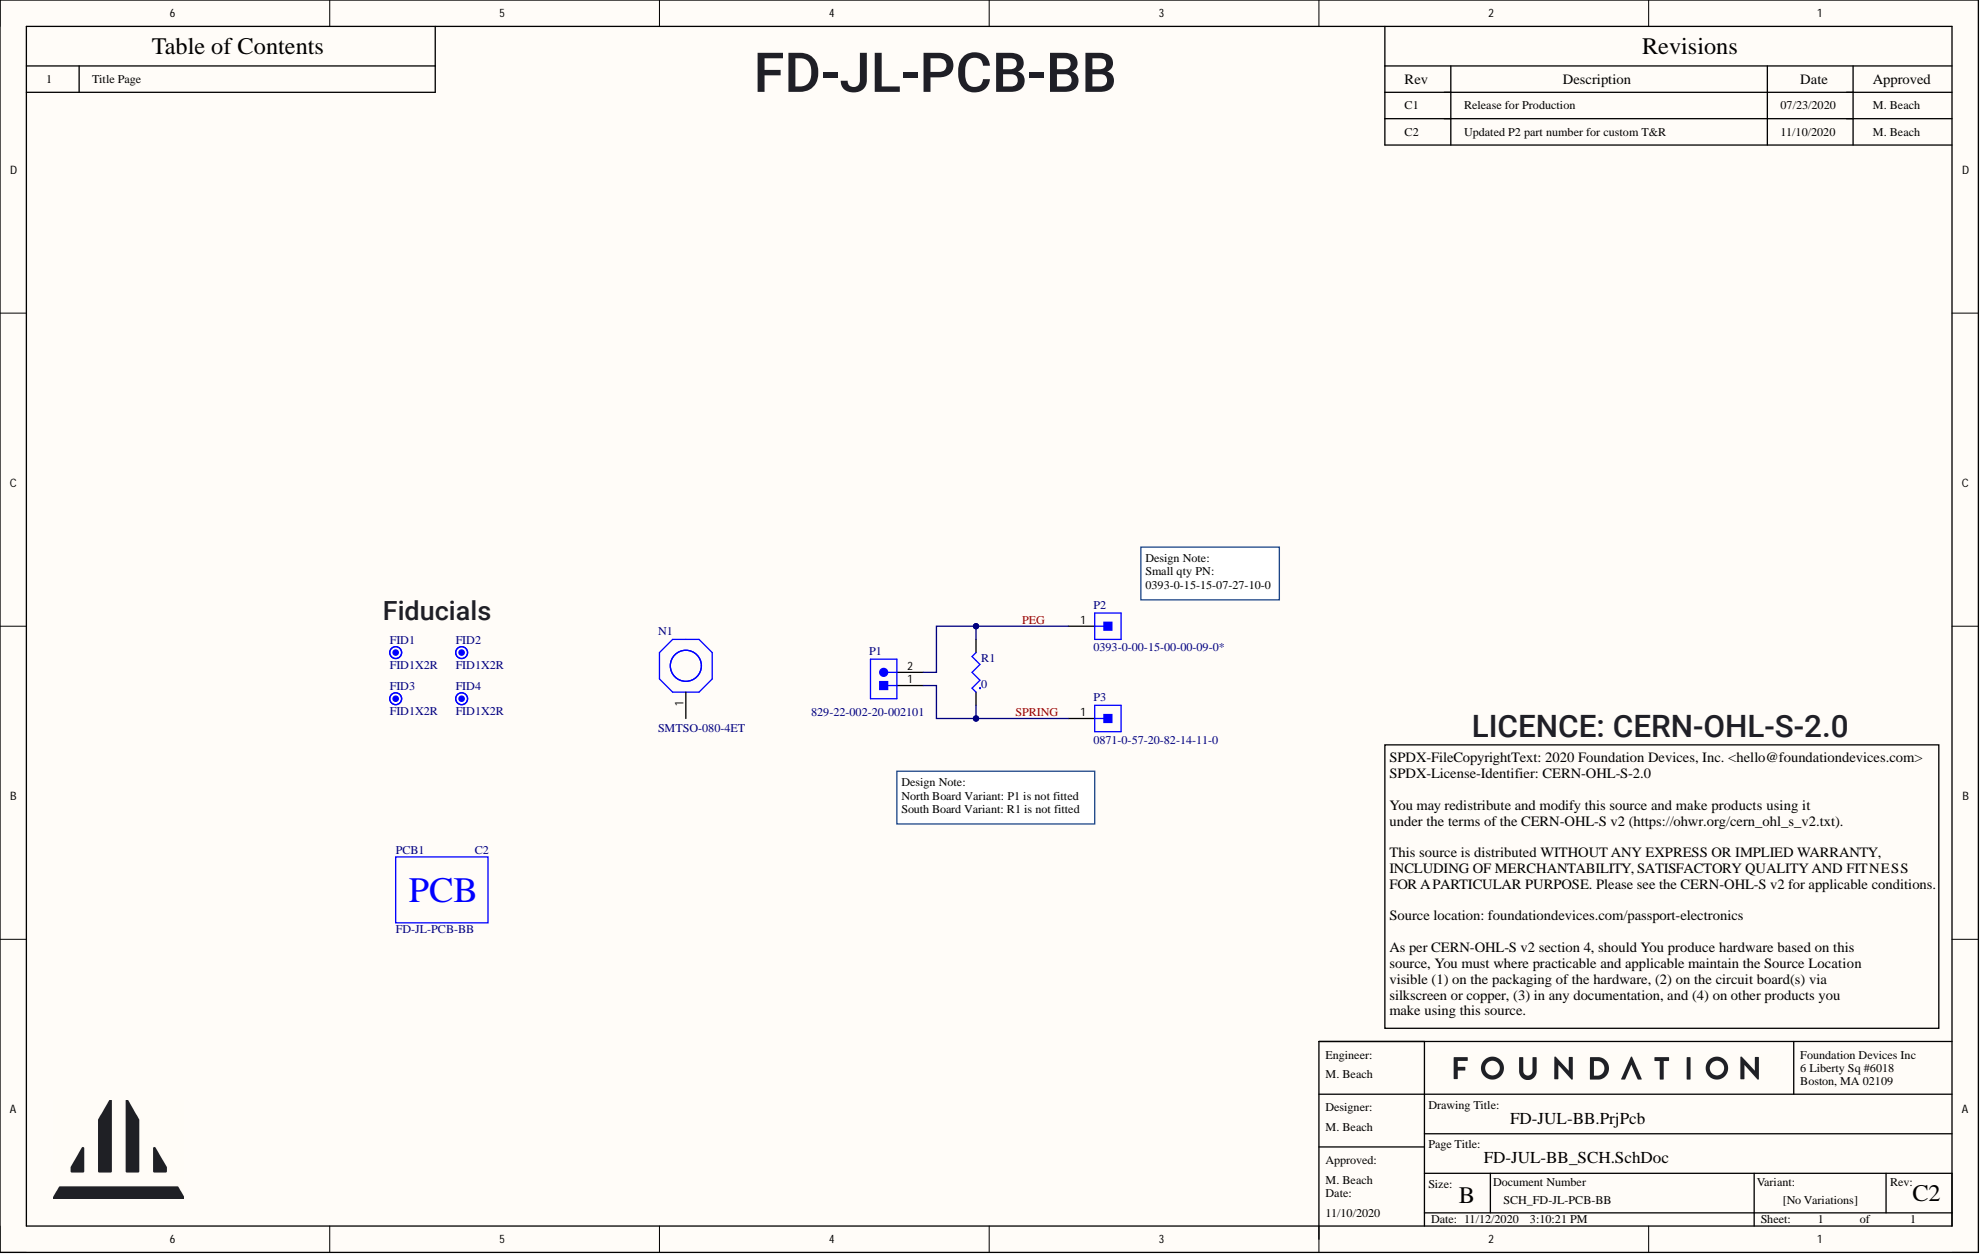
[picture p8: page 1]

Table of Contents | | Revisions

1 | Title Pag | | Rev | Description | Date | Approved

07/23/2020 | M. Beach

C2 | Updated P2 part number for custom T& R | 11/10/2020 | M. Beach

Design Note: Small qty PN:

FileCopyrightText: 2020 Foundation Devices, Inc. <hel
License-

Design Note:
North Board Variant: P1 is not fitted South Board Variant: R1 is not fitted

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

-S v2 (https://ohwr.org/cern_ohl_s_v2.txt).

This source is distributed WITHOUT
INCLUDING OF MERCHANTABI
FOR

ANY EXPRESS OR IMPL

AR PURPOSE. Please see the CERN-OHL

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

FD-JL-PCB-BB

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

You must where practicable and applicable maintain the Source Location

Engineer: | | Foundation Devices Inc 6 Liberty Sq #6018 Boston, MA 02109 M. Beach

Designer: Approved: M. Beach | Drawing Title: FD-JUL-BB.PrjPcb

Size: B | Document Number SCH_FD-JL-PCB-BB | Variant: [No Variations] | Rev : C2

Date: 11/12/2020 3:10:21 PM | | Sheet: 1 of 1

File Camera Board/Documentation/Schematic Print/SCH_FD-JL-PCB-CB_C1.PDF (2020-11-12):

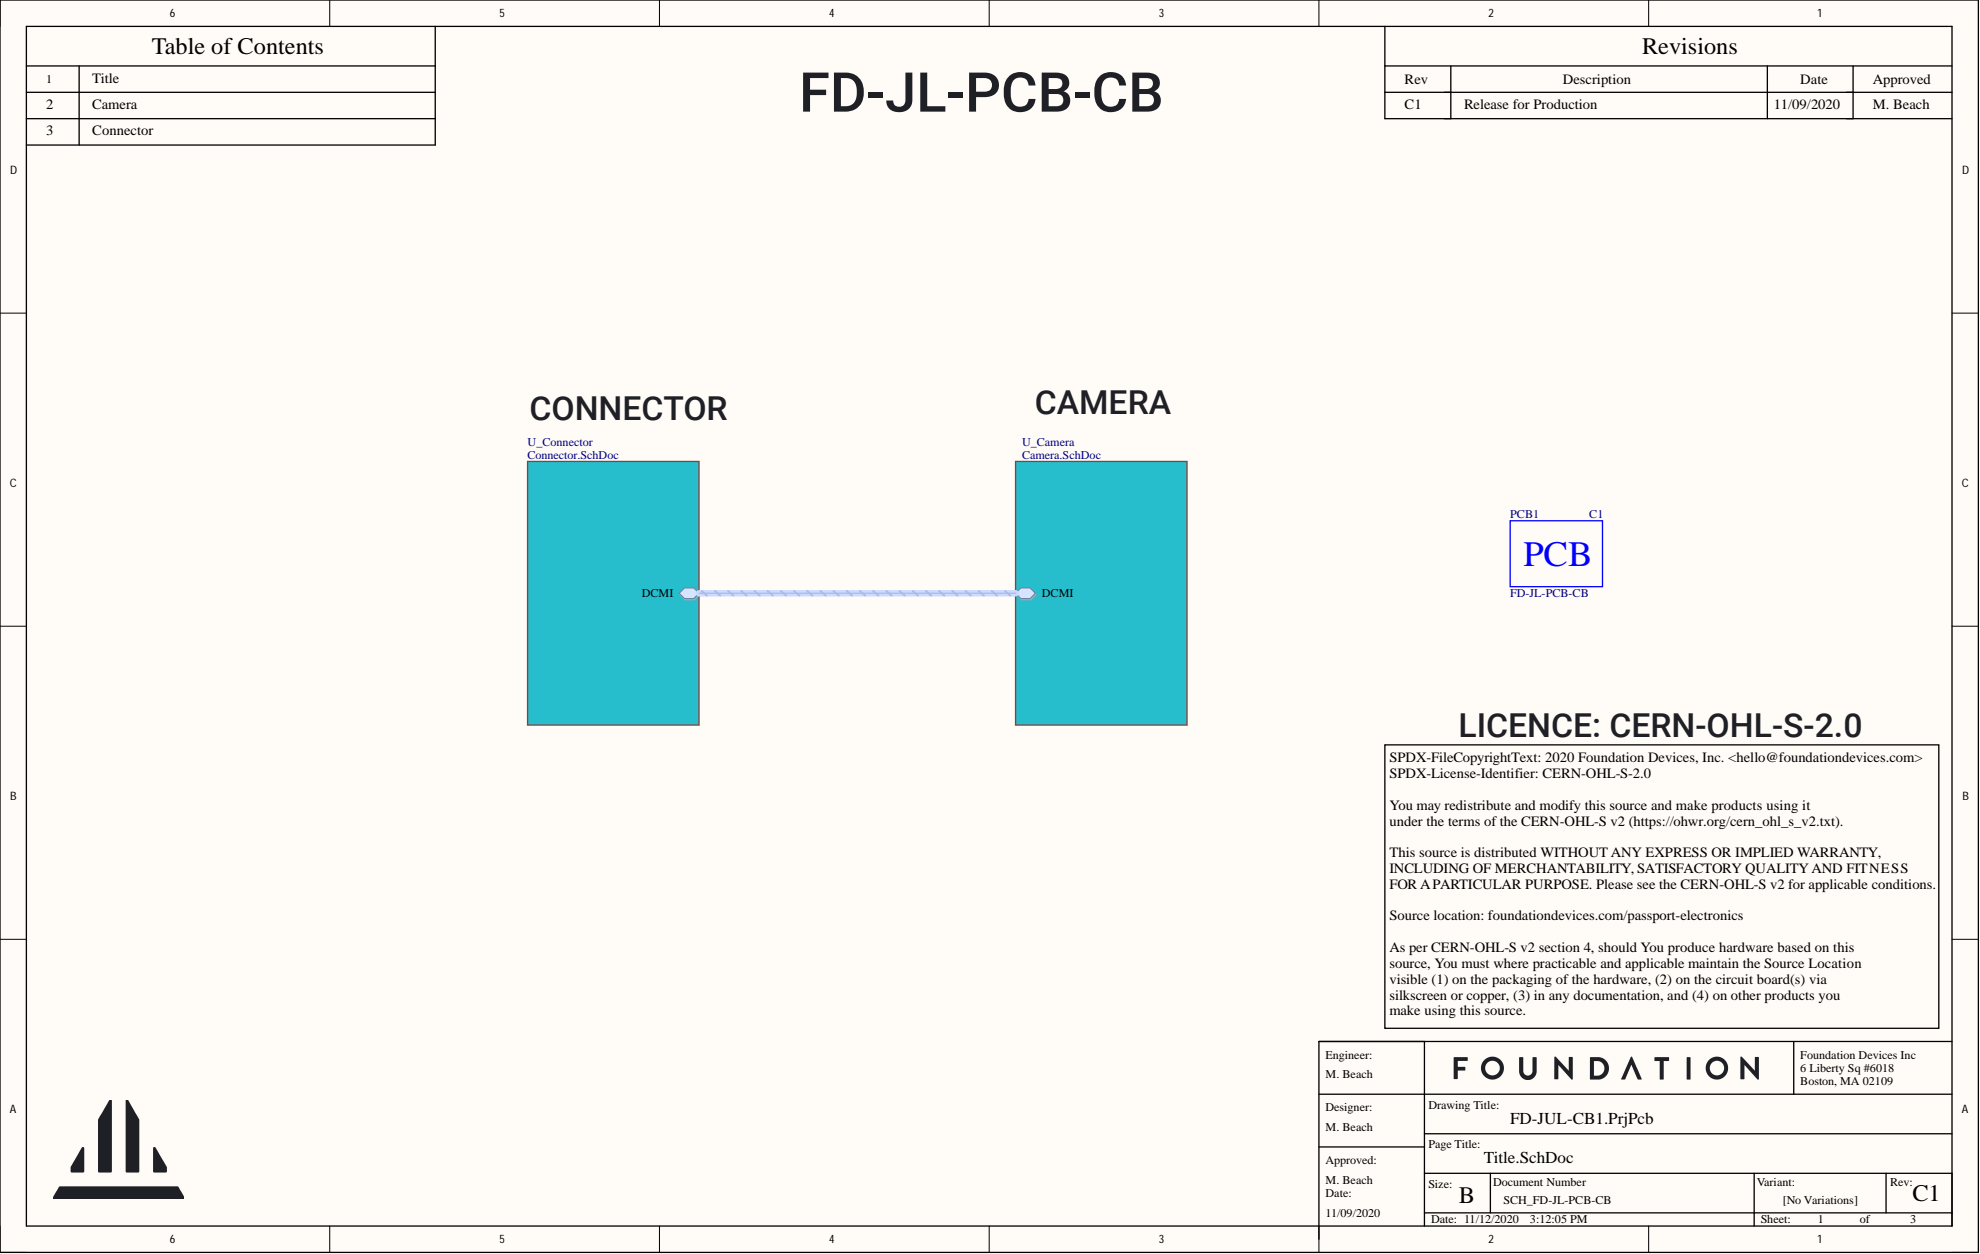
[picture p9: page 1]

Table of Contents | | Revisions

Title | | Rev | Description | Date | Approved

2 | Camera

3 | Connector

FD-JL-PCB-CB

SPDX-FileCopyrightText: 2020 Foundation Devices, Inc. <hello@foundationdevices.com>
SPDX-License-Identifier: CERN-OHL-S-2.0

You may redistribute and modify this source and make products using it
under the terms of the CERN-OHL-S v2 (https://ohwr.org/cern_ohl_s_v2.txt).

This source is distributed WITHOUT ANY EXPRESS OR IMPLIED WARRANTY,
INCLUDING OF MERCHANTABILITY, SATISFACTORY QUALITY AND FITNESS
FOR A PARTICULAR PURPOSE. Please see the CERN-OHL-S v2 for applicable conditions.

Source location: foundationdevices.com/passport-electronics

As per CERN-OHL-S v2 section 4, should You produce hardware based on this
source, You must where practicable and applicable maintain the Source Location
visible (1) on the packaging of the hardware, (2) on the circuit board(s) via
silkscreen or copper, (3) in any documentation, and (4) on other products you
make using this source.

Engineer: | | Foundation Devices Inc 6 Liberty Sq #6018 Boston, MA 02109 M. Beach

Designer: M. Beach | Drawing Title: FD-JUL-CB1.PrjPcb

Size: B | Document Number SCH_FD-JL-PCB-CB | Variant: [No Variations] | Rev: C1

Date: 11/12/2020 3:12:05 PM | | Sheet: 1 of 3

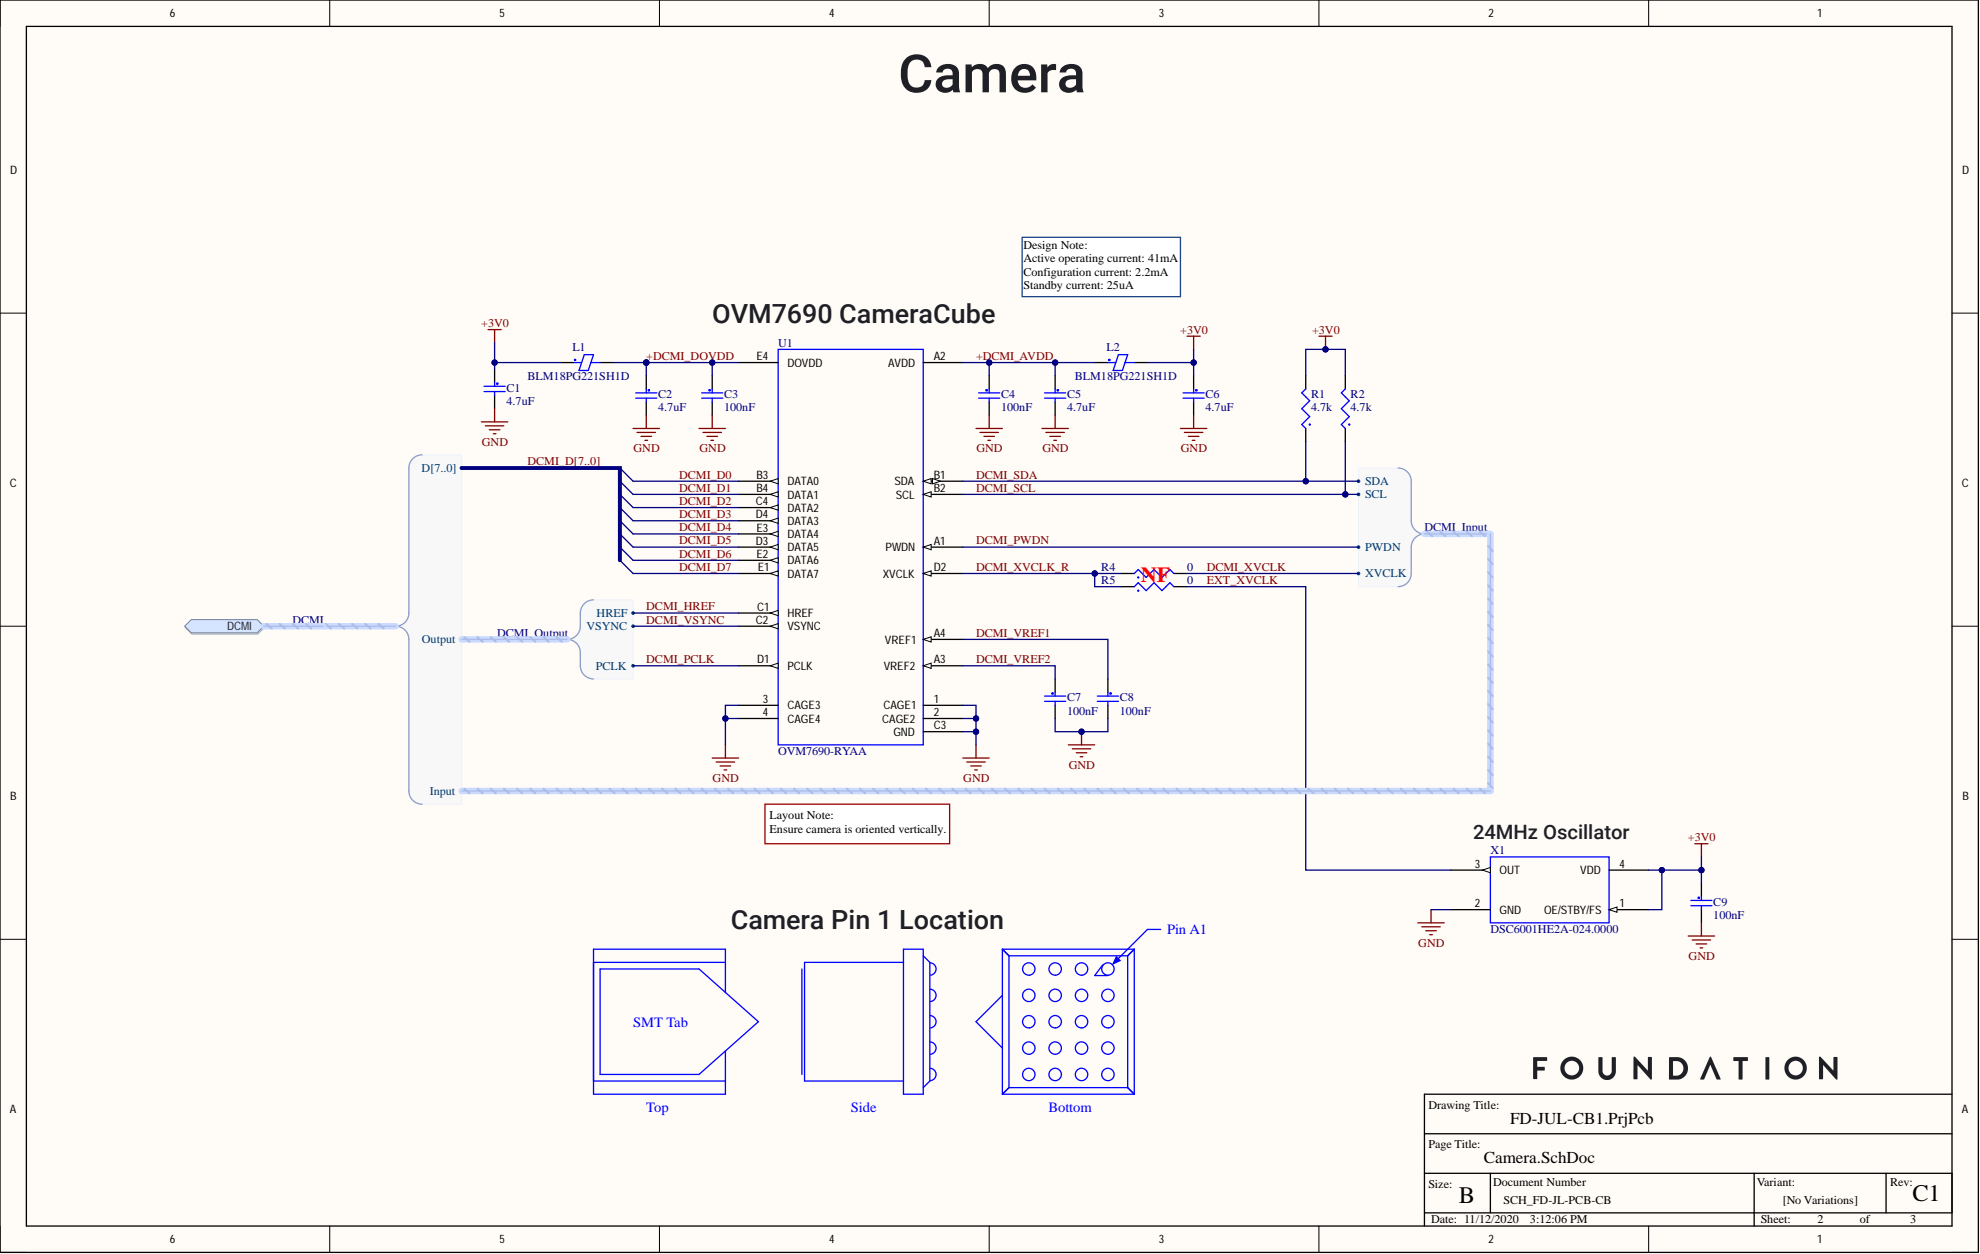
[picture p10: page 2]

Design Note: Active operating current: 41m

Ensure camera is oriented vertically

Size: B | Document Number SCH_FD-JL-PCB-CB | Variant: | Rev :

3:12:06 PM | | Sheet: 2 of

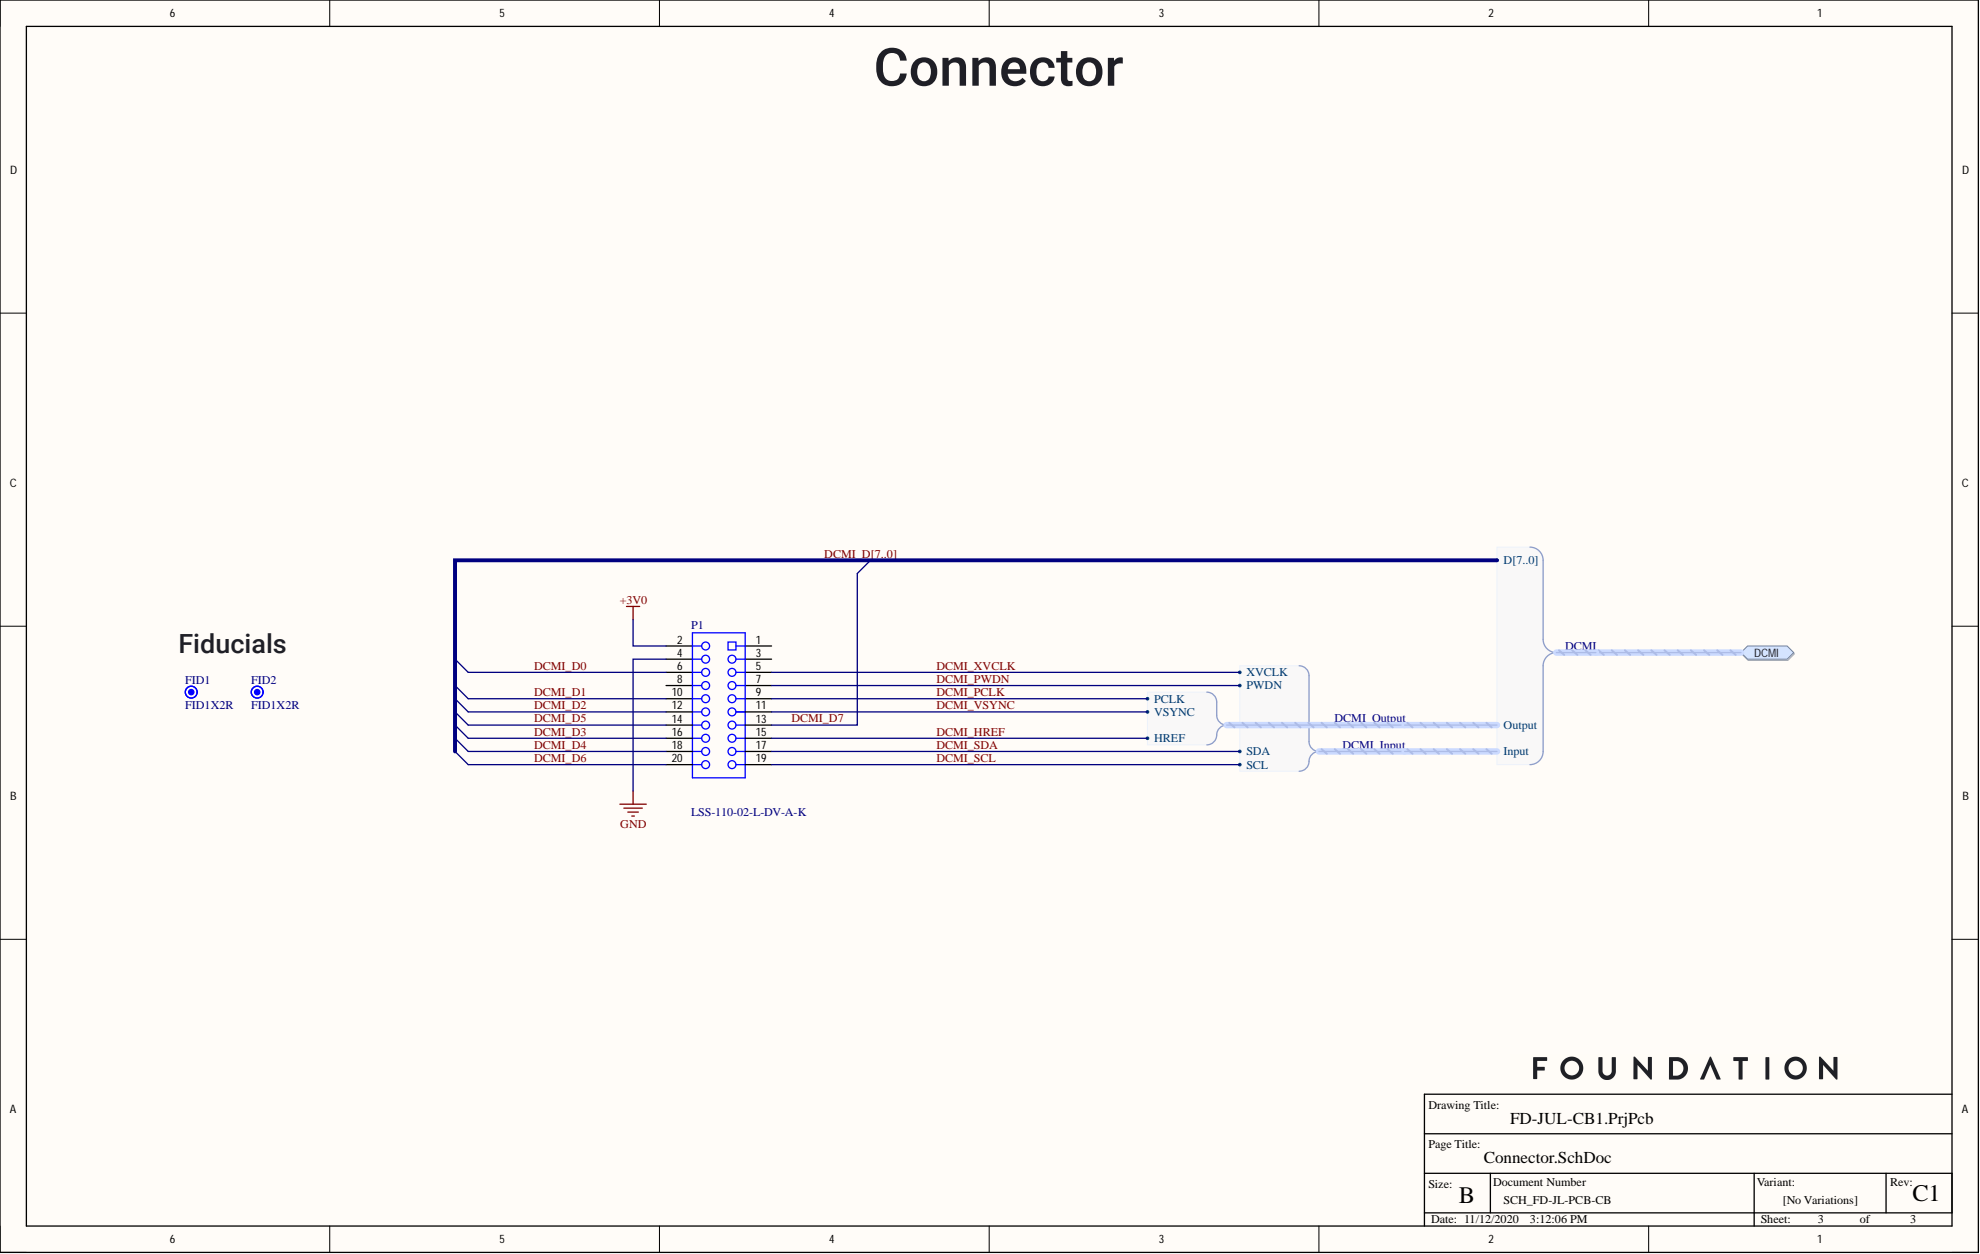
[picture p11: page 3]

Size: B | Document Number SCH_FD-JL-PCB-CB | Variant: | Rev :

3:12:06 PM | | Sheet: 3 of

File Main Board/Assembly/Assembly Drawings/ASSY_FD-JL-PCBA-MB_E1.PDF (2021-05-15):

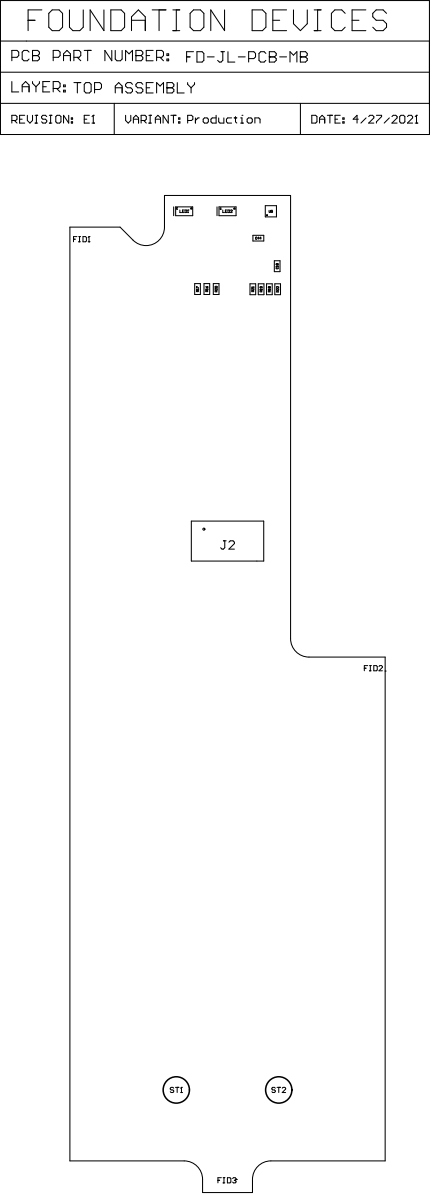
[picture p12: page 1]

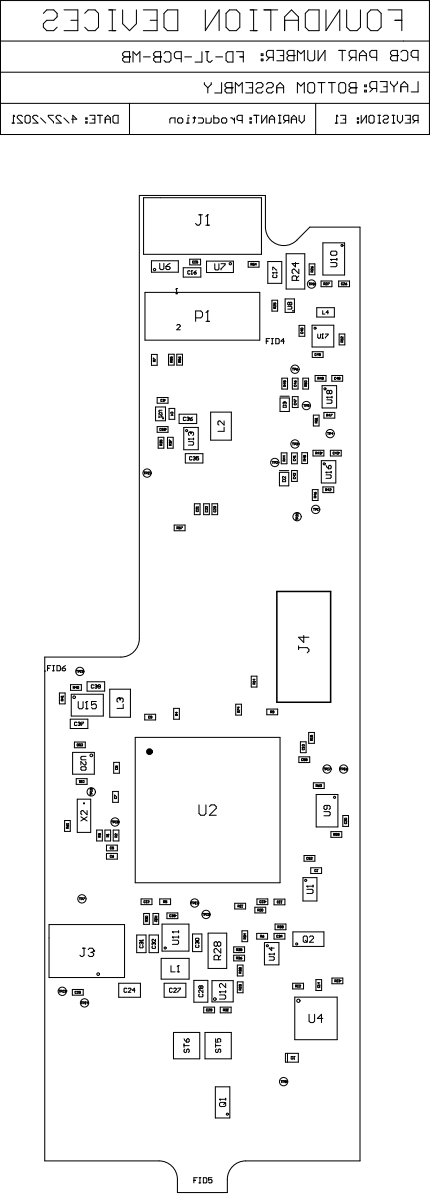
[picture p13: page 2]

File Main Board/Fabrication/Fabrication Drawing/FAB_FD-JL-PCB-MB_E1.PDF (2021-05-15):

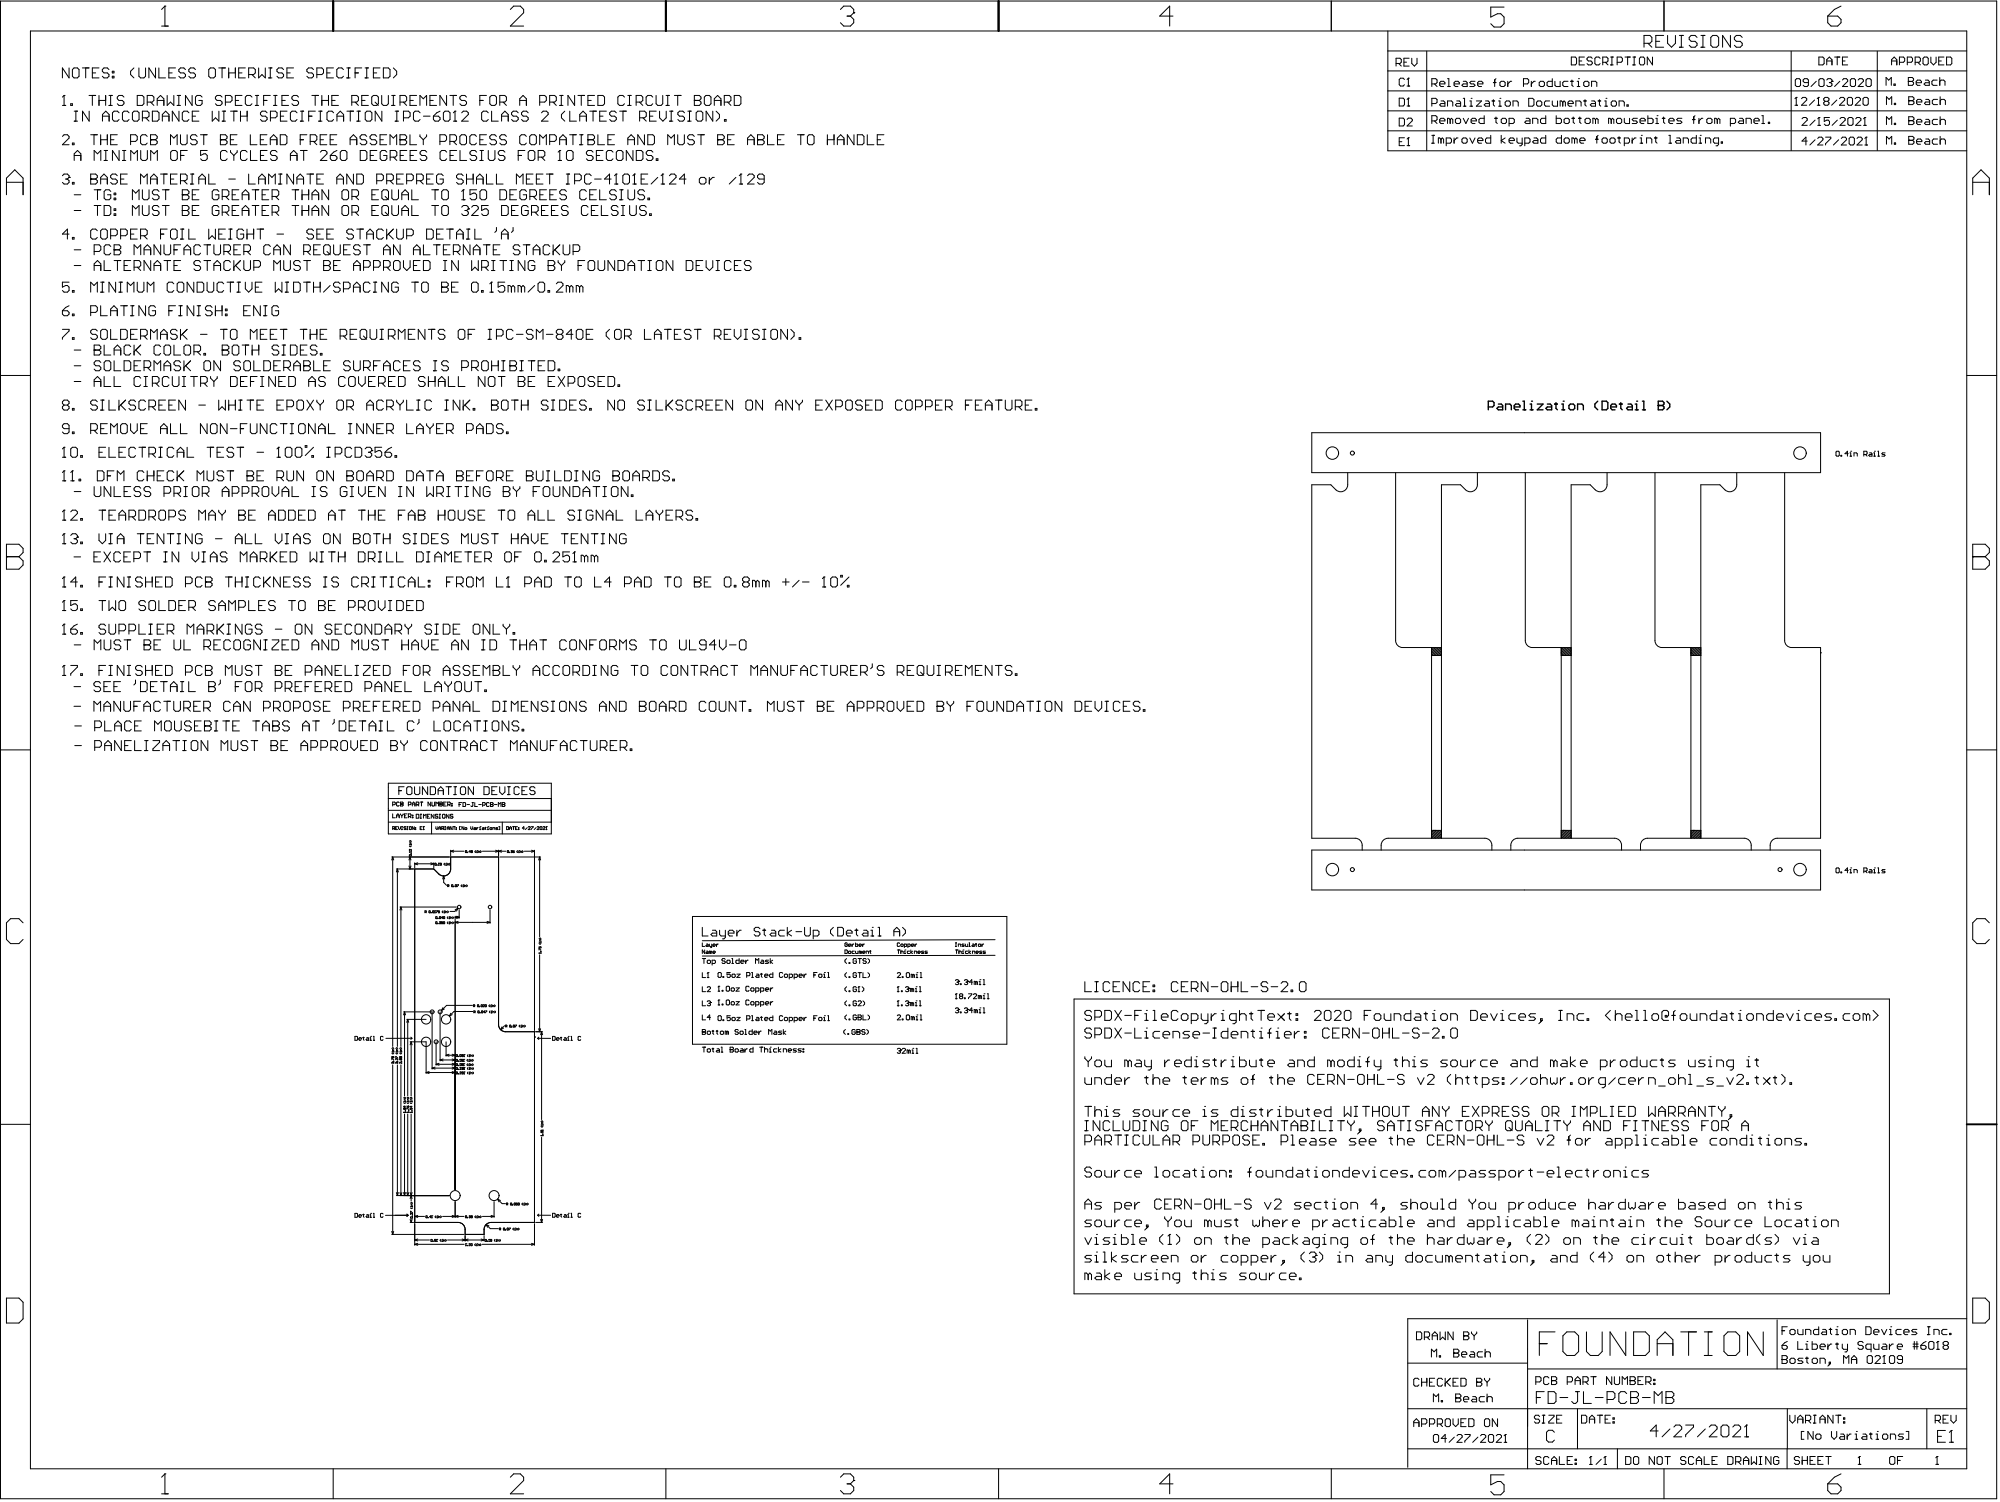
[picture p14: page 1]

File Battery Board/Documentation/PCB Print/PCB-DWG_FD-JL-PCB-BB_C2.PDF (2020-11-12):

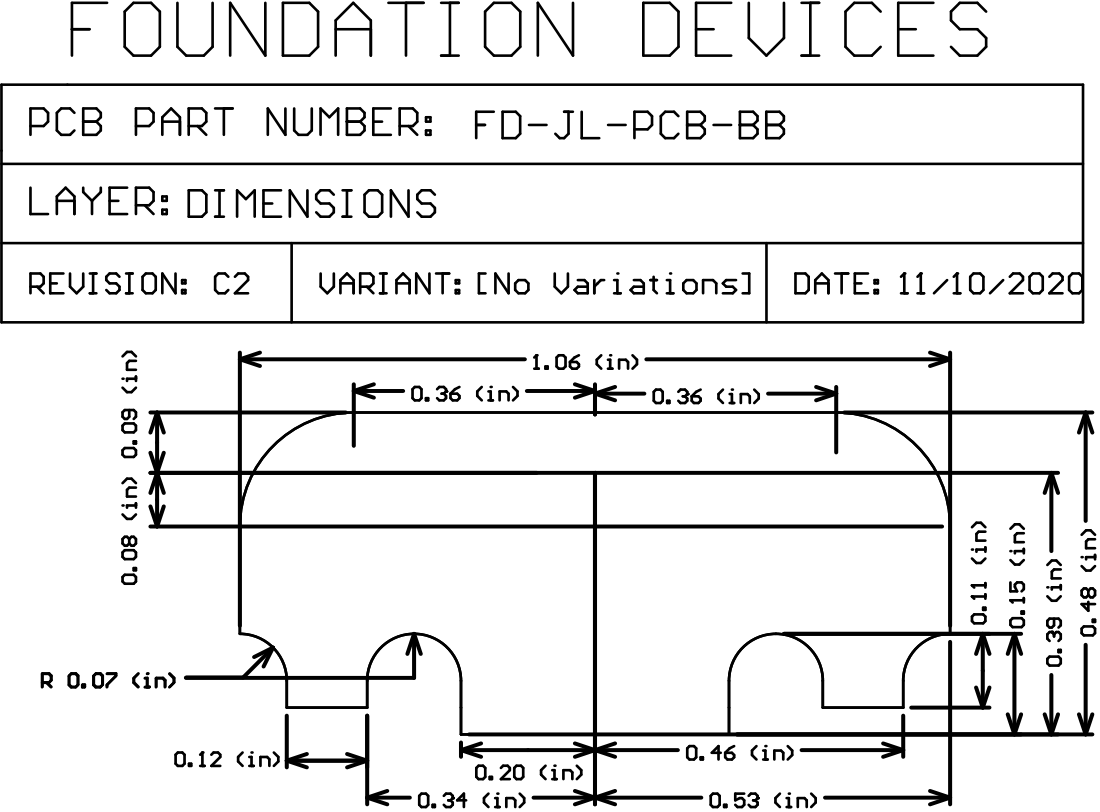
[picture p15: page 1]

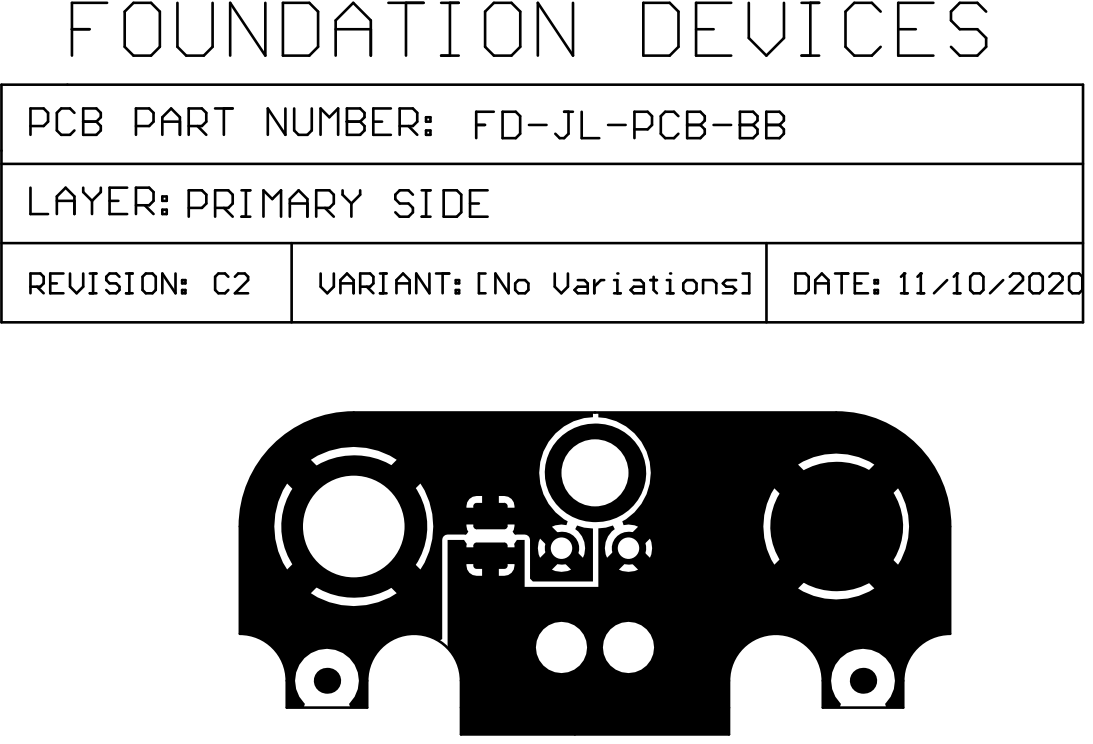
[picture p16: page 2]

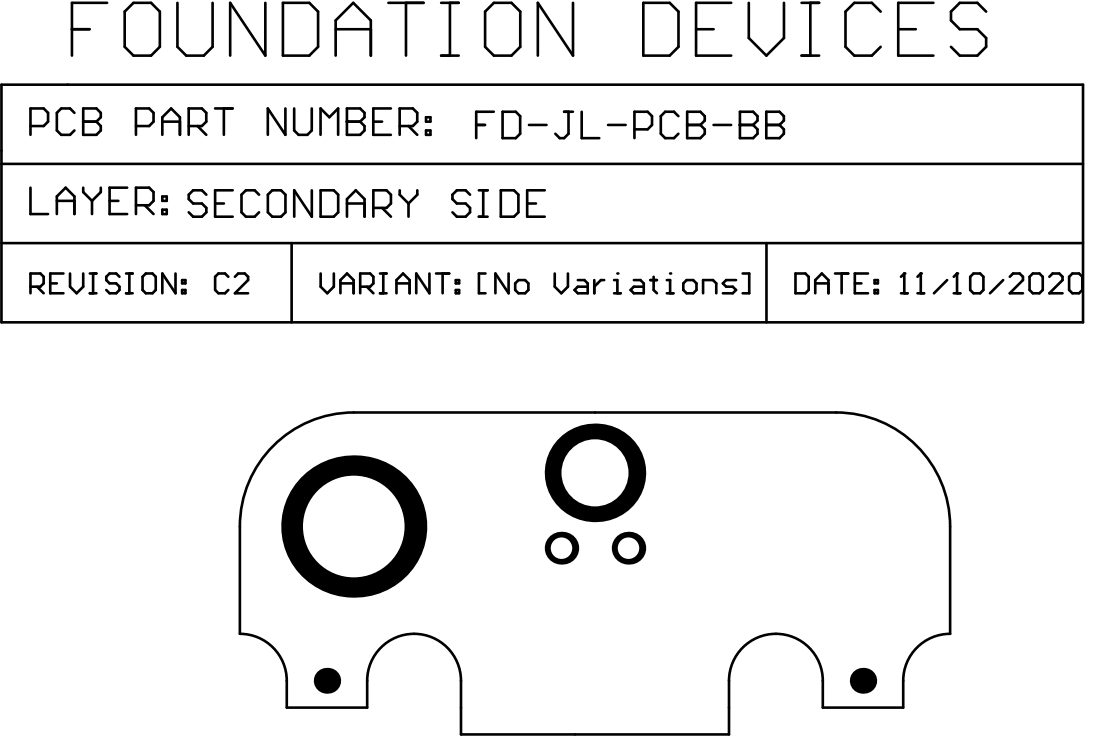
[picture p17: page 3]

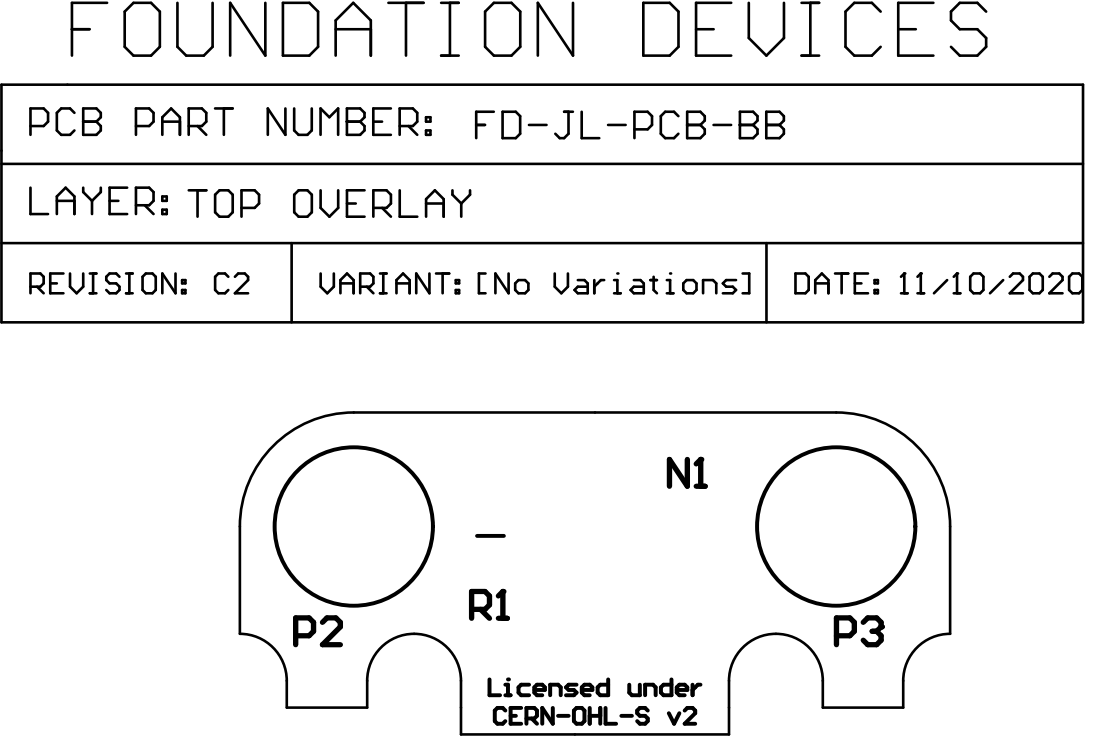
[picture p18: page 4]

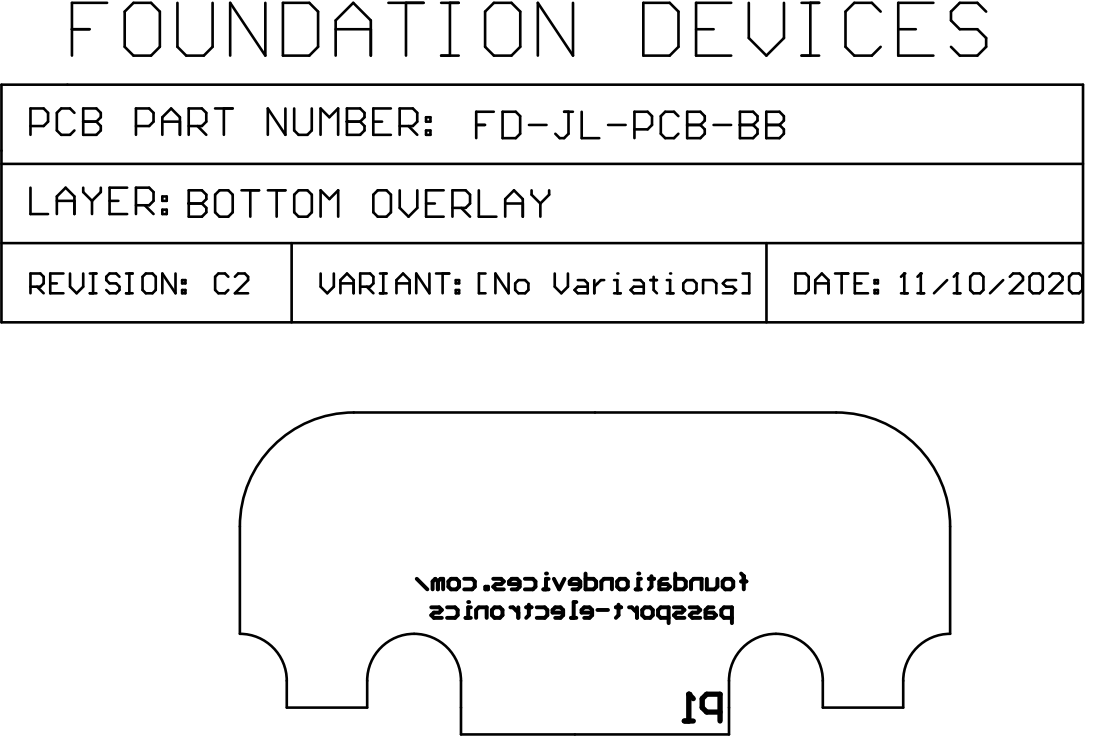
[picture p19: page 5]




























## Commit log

2020-11-12 Updated schematic files
2021-05-15 production release
    [BOM_FD-JL-PCBA-MB_C1.csv, BOM_FD-JL-PCBA-MB_C1.xlsx, BOM_FD-JL-PCBA-MB_E1.csv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]
